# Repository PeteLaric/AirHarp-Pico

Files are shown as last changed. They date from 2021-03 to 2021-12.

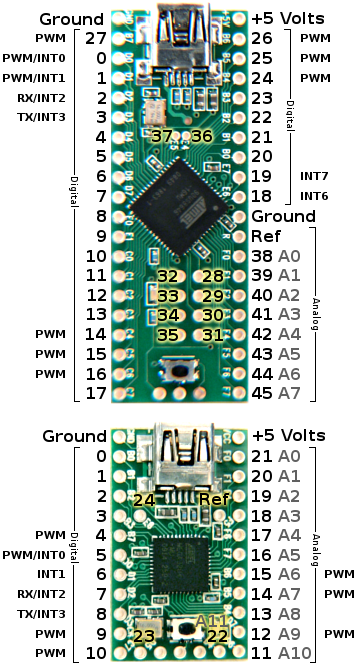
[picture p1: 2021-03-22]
misc/wiring_pinout2.png

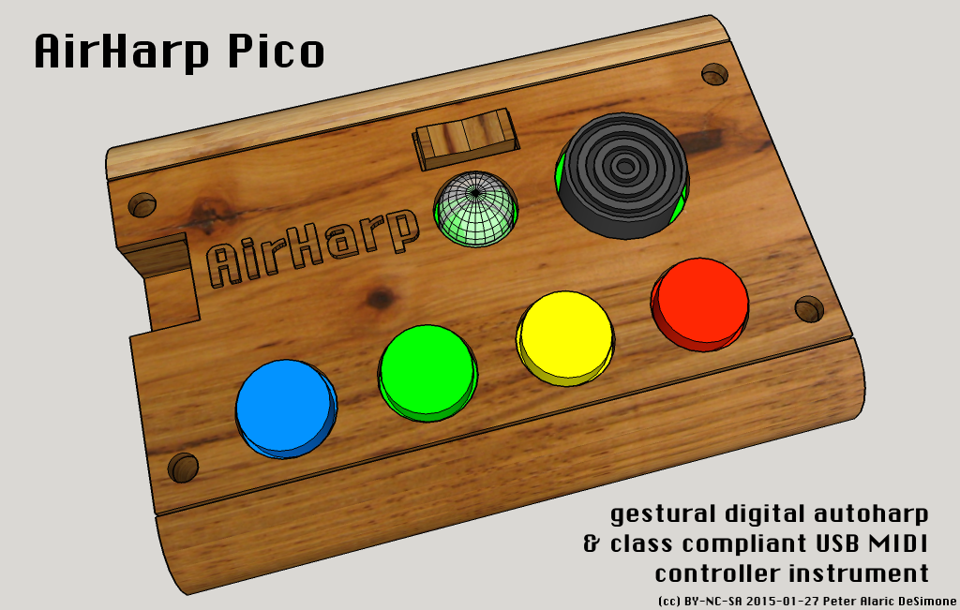
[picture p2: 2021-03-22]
render/AirHarp Pico 002 wood.png

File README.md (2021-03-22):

# AirHarp-Pico
A gestural autoharp that functions as a class-compliant USB MIDI controller instrument.

http://www.AirHarp.com

Originally conceived in 2010, the AirHarp is a gestural autoharp that allows the musician to strum chords on an invisible beam of ultrasound.  For several years, I manufactured and sold these musical instruments online.  The entire project is open source.  If you build one, please send me a note!  I'd love to see it.

Cheers,

~ Pete

http://www.PeteLaric.com

PeteLaric@protonmail.com

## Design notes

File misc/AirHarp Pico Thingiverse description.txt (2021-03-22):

AirHarp Pico
http://www.thingiverse.com/thing:676726

The AirHarp is a gestural digital autoharp that allows you to strum chords in the air on a beam of ultrasound!  The AirHarp Pico is the newest instrument in our line, with an impending Kickstarter campaign to manufacture them in quantity.  It's the best AirHarp yet, and we're confident that our customers will agree with us!

For more, check out http://www.airharp.com

Tags:

AirHarp, autoharp, MIDI controller, ultrasound, ultrasonic rangefinder, Maxbotix, Lyratron

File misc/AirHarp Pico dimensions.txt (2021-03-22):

AirHarp Pico dims
PCB: 2.8 x 1.7" (71.12 x 43.18 mm)

part locations:
part		imperial	metric
LED		<1.5, 1.1>	<38.1, 27.94>
transpose down  <1.4, 1.5>	<35.56, 38.1>
transpose up	<1.7, 1.5>	<43.18, 38.1>
S4		<.35, 0.3>	<8.89, 7.62>
RX pin		<1.95, 1.15>	<49.53, 29.21>

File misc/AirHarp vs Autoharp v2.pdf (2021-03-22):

# AirHarp vs. Autoharp

## an unfair comparison

AirHarp Pico by Lyratron | Autoharp by Oscar Schmidt

Never goes out of tune.

Goes out of tune all the damn time. Difficult and time-consuming to re-tune.

Extremely lightweight; only 3 ounces! | Heavy; shipped weight is 10.2 pounds!
Tiny; about the size of a pack of cigarettes. | Bulky; about the size of a briefcase.
Automatic transpose; play the same song in any key with the exact same fingering. | Transposing requires completely different fingering and knowledge of music theory.
Can sound like any instrument; a harp, pipe organ, electric guitar - you name it! | You're stuck with one tinny, twangy sound forever.
Play any chord without shifting your grip. | Awkward finger gymnastics.
$100 direct from Lyratron (http://www.lyratron.com/) | $289 on Amazon (http://www.amazon.com/Oscar-Schmidt-21-Chord-Autoharp/dp/B0002KMTLG)

AirHarp® is a registered trademark of Peter Alaric DeSimone. (http://www.peteralaric.com/)

Autoharp was a registered trademark of International Musical Corporation, but its registration has expired, and it is now considered a generic descriptive term for that type for instrument.

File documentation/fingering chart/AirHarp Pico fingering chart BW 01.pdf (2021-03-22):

AirHarp® Pico

Fingering Chart

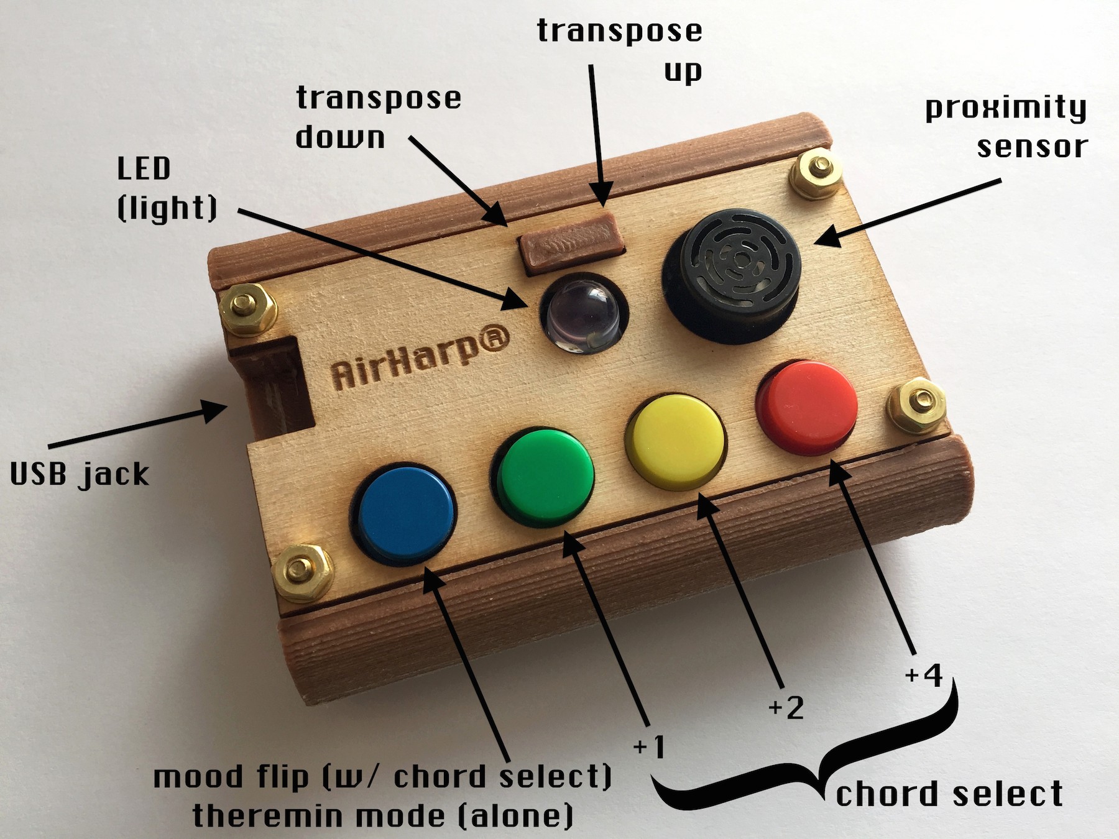
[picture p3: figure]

(cc) 2015 BY Peter Alaric DeSimone

Silence | Theremin Mode

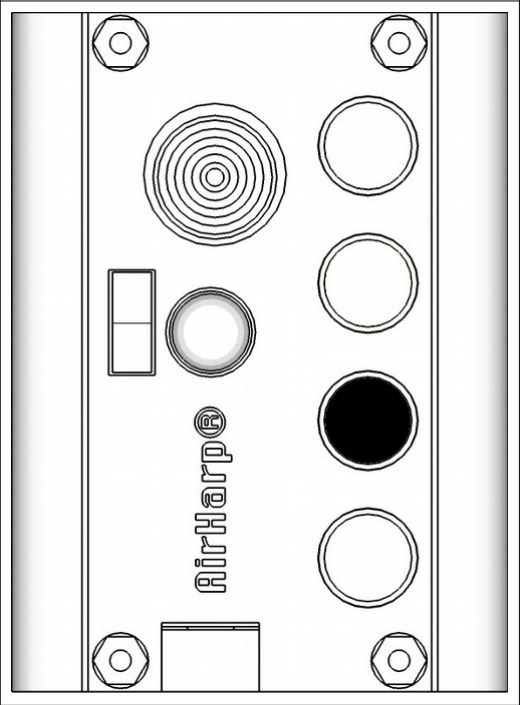
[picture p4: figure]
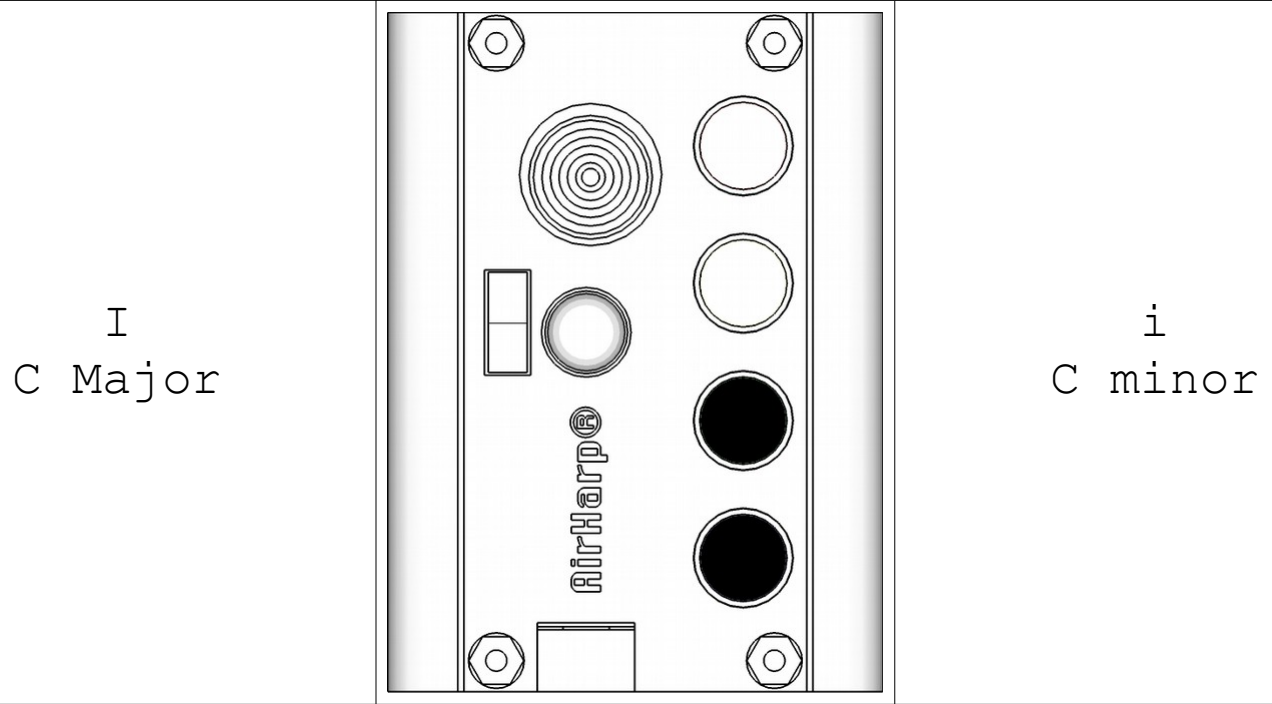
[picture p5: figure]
I C Major; i C minor
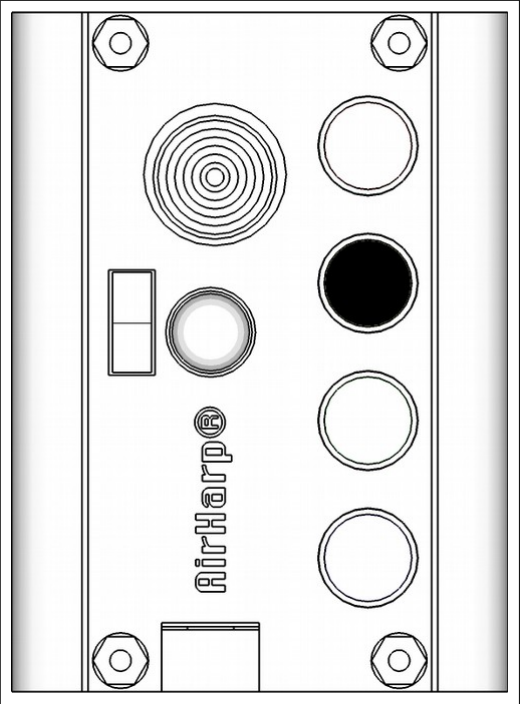
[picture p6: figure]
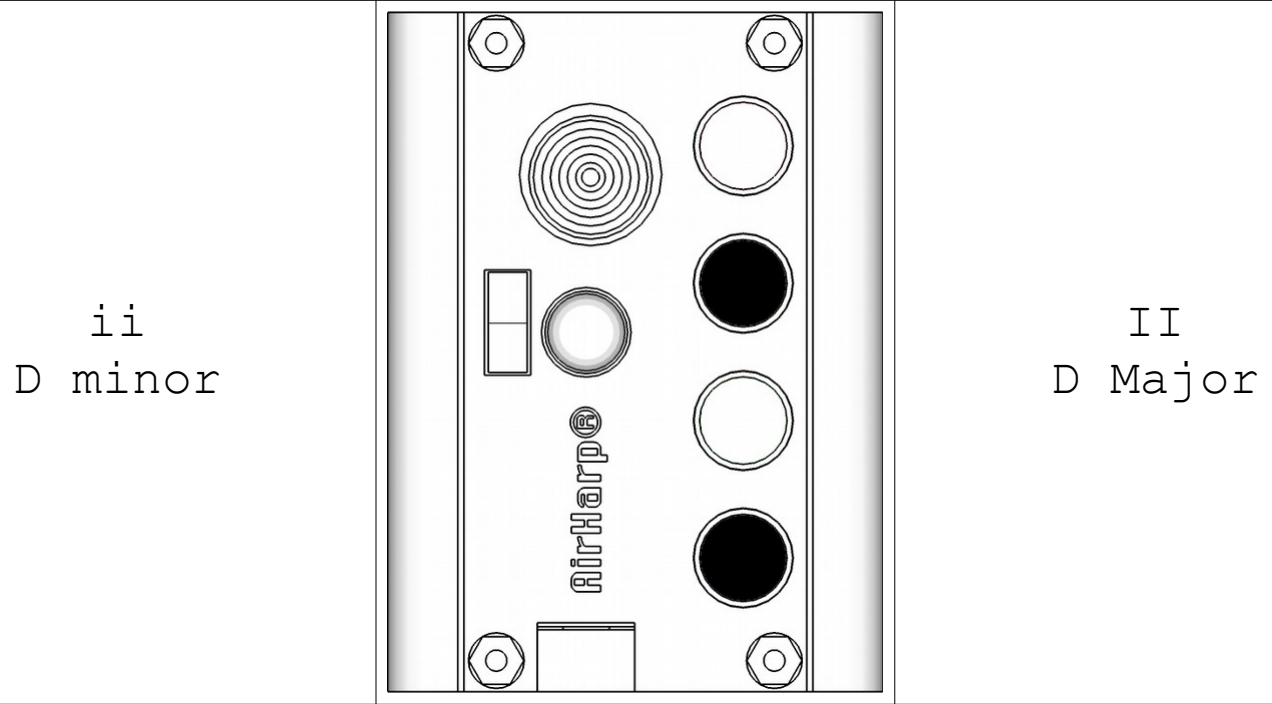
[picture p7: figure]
ii D minor; II D Major
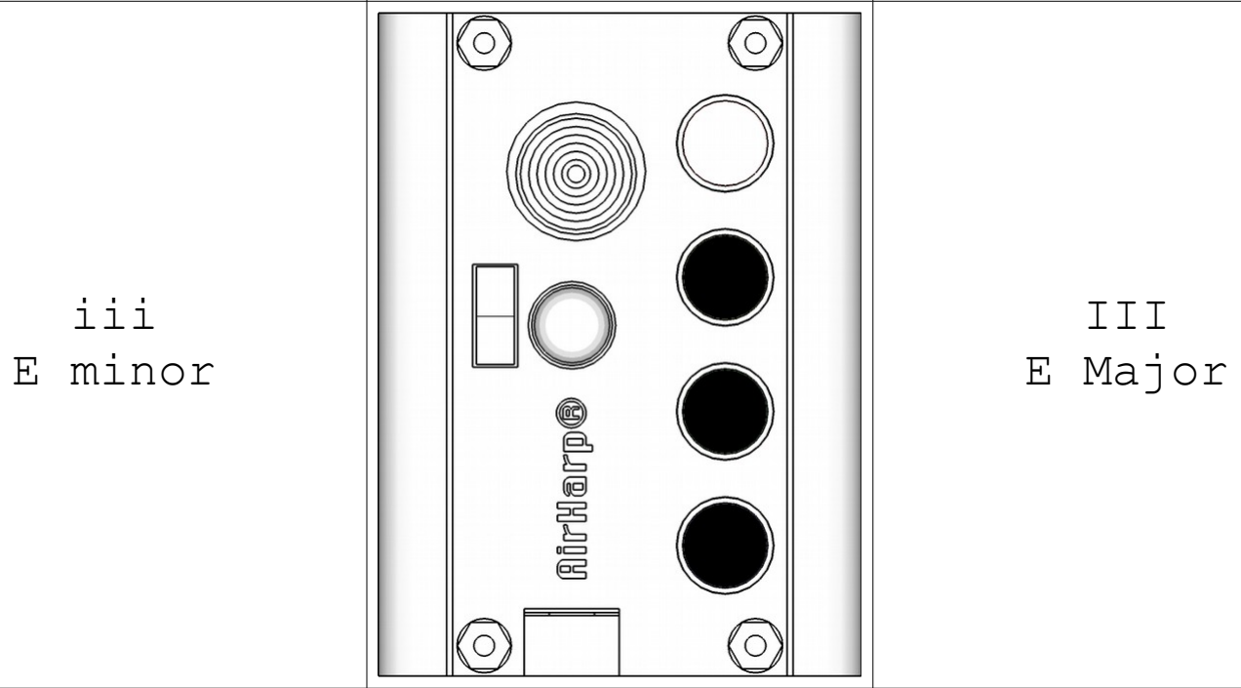
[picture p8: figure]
iii E minor; III E Major
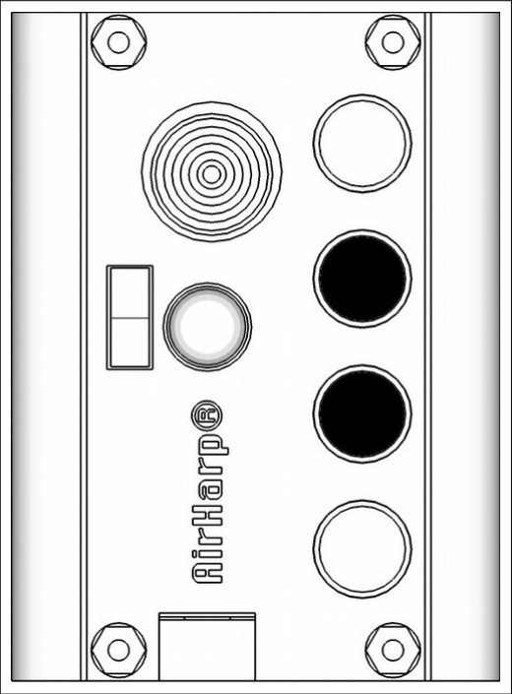
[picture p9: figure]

IV F Major | iv F minor

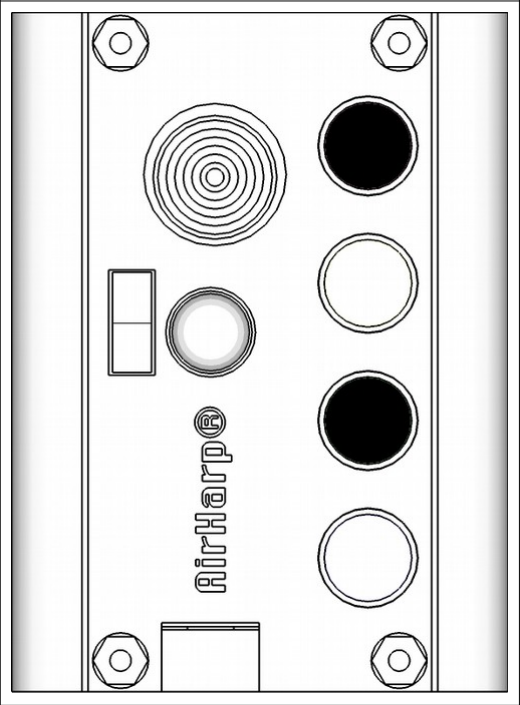
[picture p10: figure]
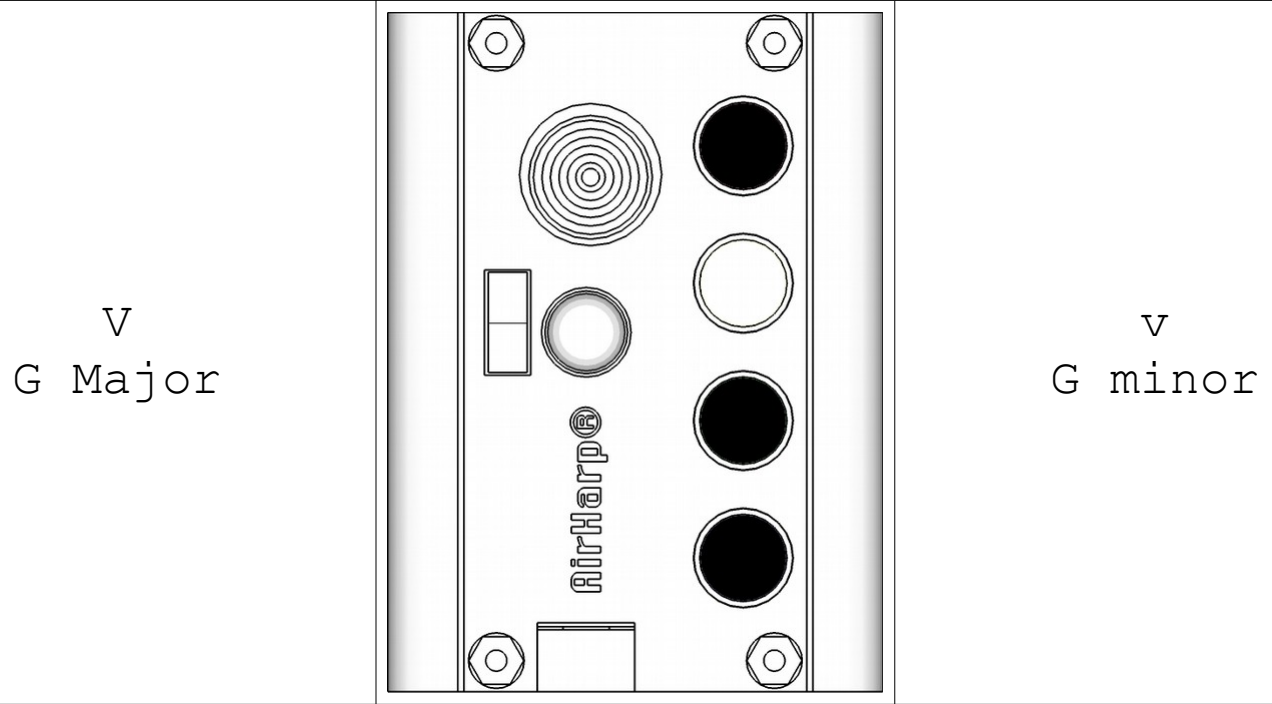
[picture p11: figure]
V G Major; v G minor
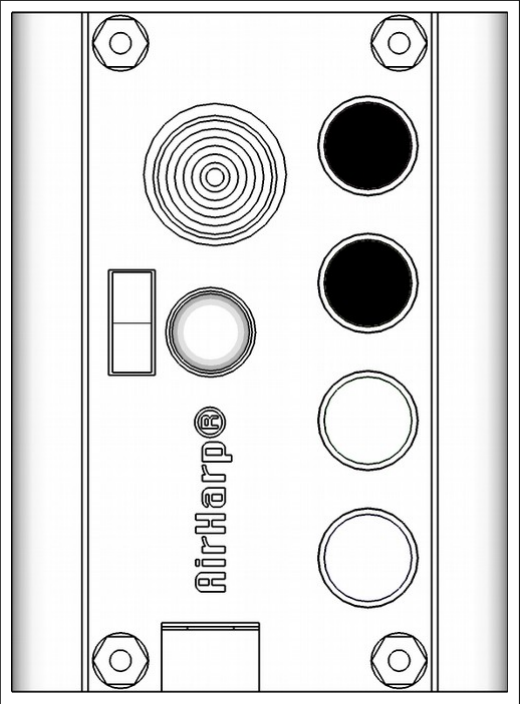
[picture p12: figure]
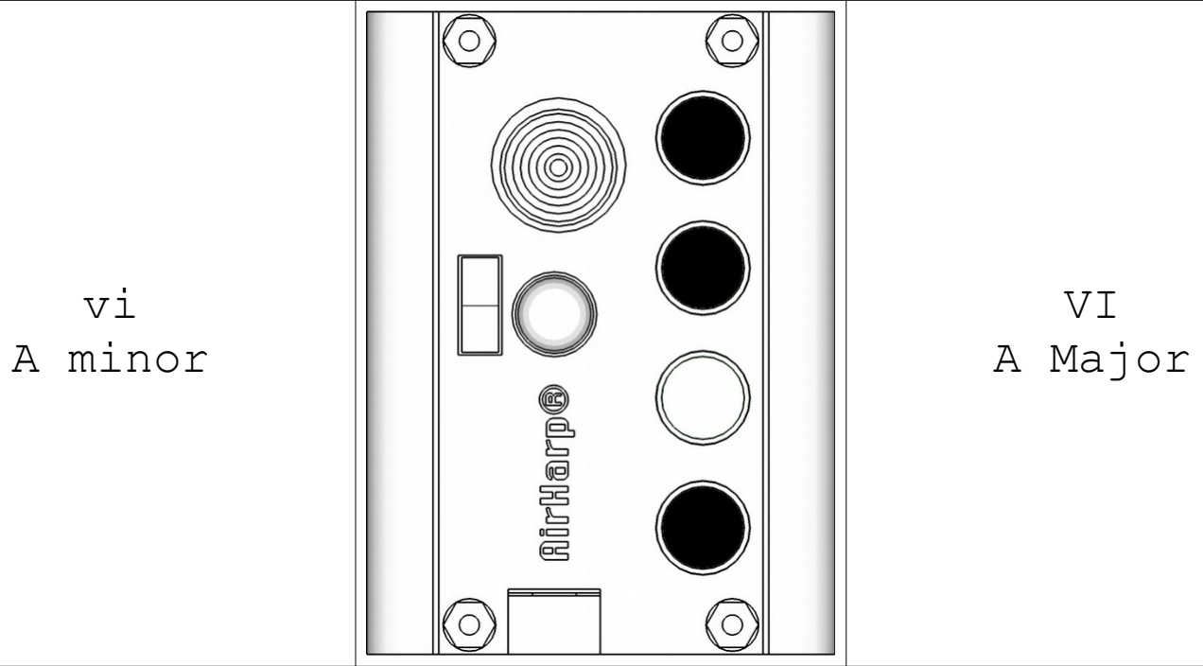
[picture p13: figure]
vi A minor; VI A Major
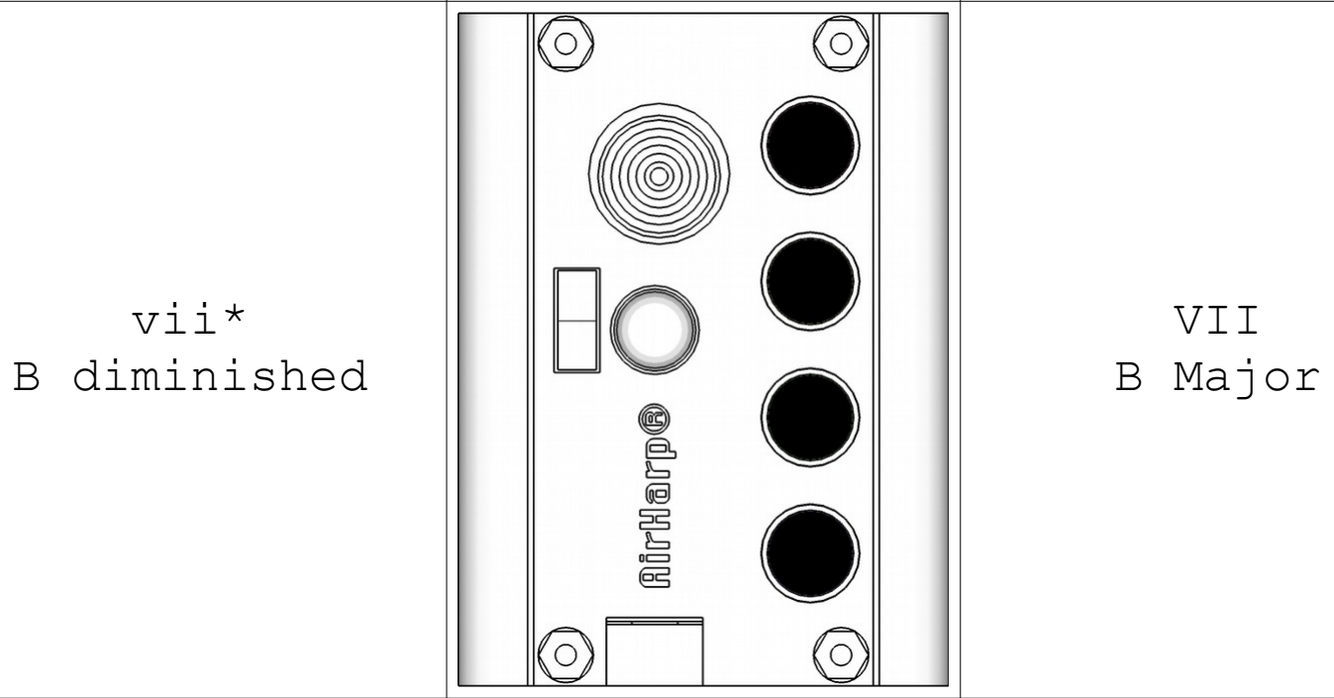
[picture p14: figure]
vii* B diminished; VII B Major
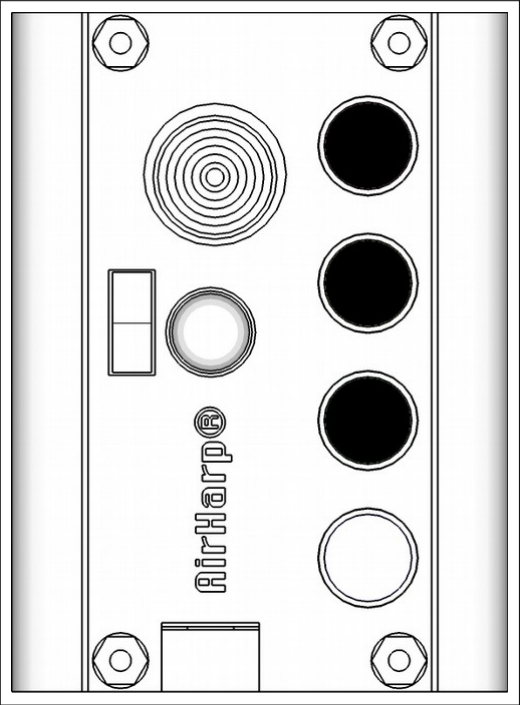
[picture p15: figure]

Transpose Up
½ Step

Transpose Down
½ Step

General Usage Notes

The AirHarp® Pico defaults to the key of C Major on boot, but can be tuned to any major key using the Transpose Up/Down buttons. To play in a minor key, simply tune to the desired key's relative major (3 half steps up from the minor key's tonic). For example, to play in the key of A minor, you would tune to the key of C Major. Since this is the AirHarp's default tuning, you don't have to do any transposing to play in the key of A minor. To play in B minor, you would tune to D Major. To achieve this, you would press the Transpose Up button twice, transposing up a whole step from C Major to D Major.

For an AirHarp to trigger a note, two conditions must be met:

1. One of the chord select buttons must be depressed.
2. The musician's hand (or some other object) must be within a predefined distance of the ultrasonic rangefinder. By default, this range is somewhere in the neighborhood of one meter.

If either one of these conditions is not met, no sound will be heard. This is by design; as with any real musical instrument, playing a note is a deliberate act, not something likely to happen by accident.

Care should be taken to avoid wiggling the USB connector while plugged into the AirHarp's USB jack. This can result in lost data packets and erratic behavior of your harp. If erratic behavior should be observed (e.g. stuck notes), simply unplug and replug your AirHarp to reboot it. Stuck notes may need to be cleared in your DAW software, which can usually be accomplished by pressing play and then pause. In Apple Logic and Apple GarageBand, simply hit the spacebar key twice.

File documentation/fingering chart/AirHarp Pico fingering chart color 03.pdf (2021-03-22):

AirHarp® Pico

Fingering Chart


(cc) 2015 BY Peter Alaric DeSimone

Silence | Theremin Mode

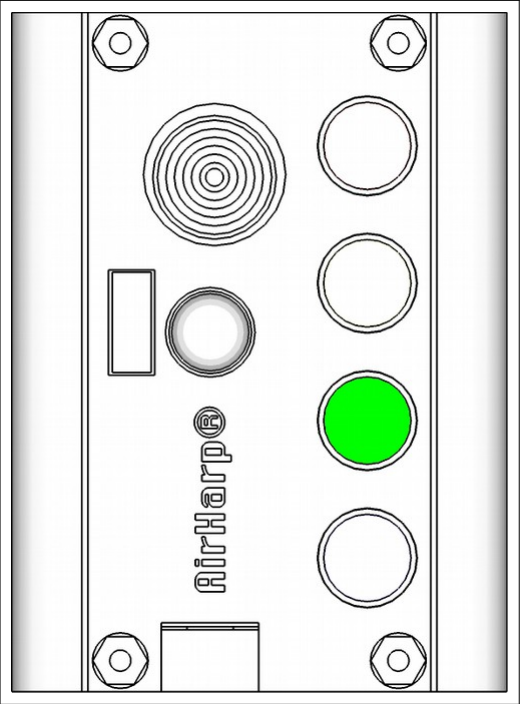
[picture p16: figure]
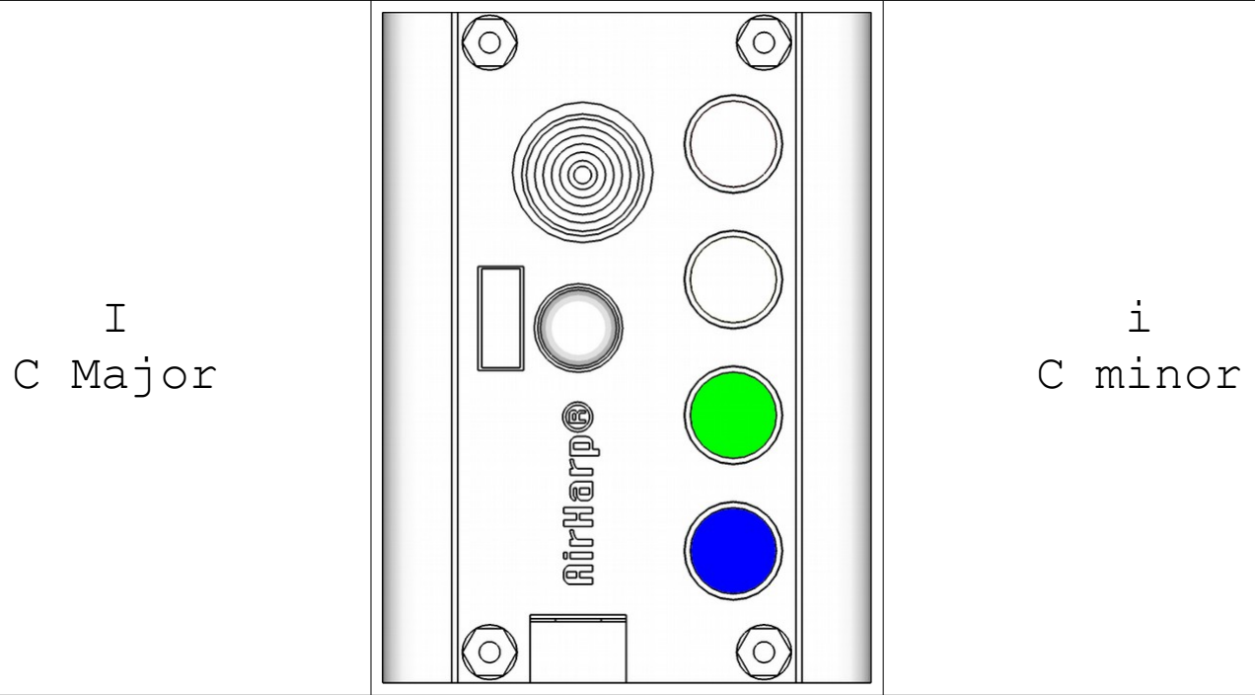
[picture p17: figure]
I C Major; i C minor
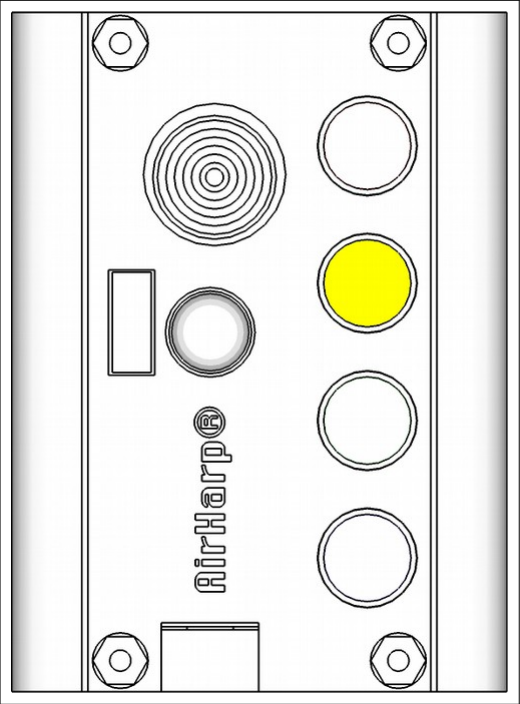
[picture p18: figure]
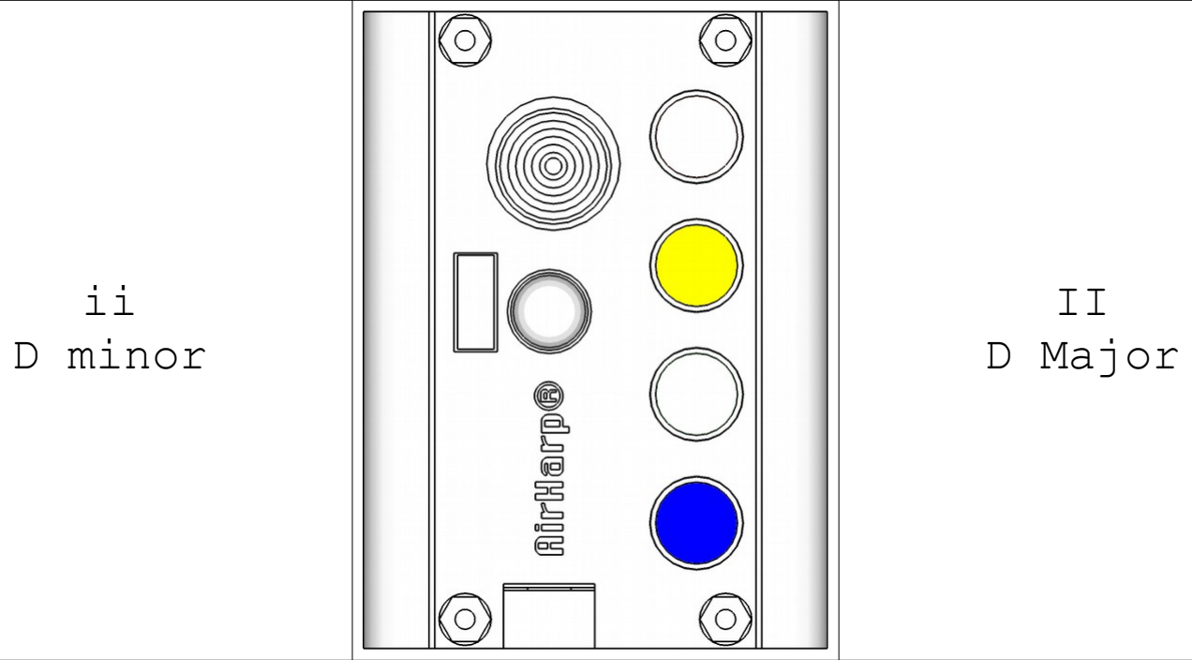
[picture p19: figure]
ii D minor; II D Major
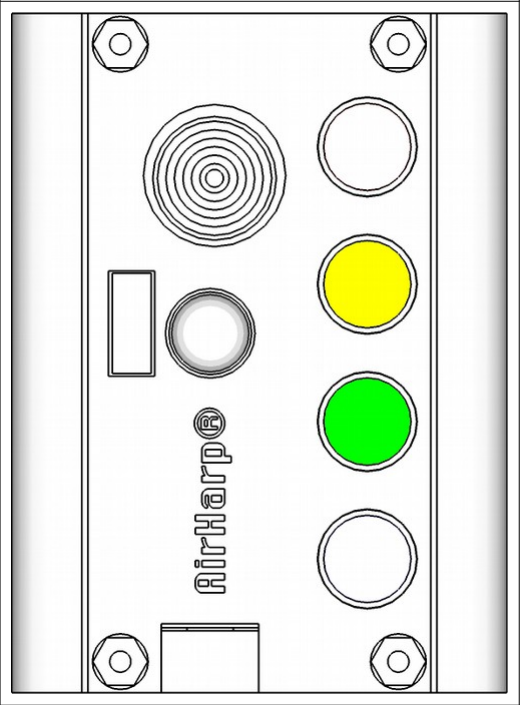
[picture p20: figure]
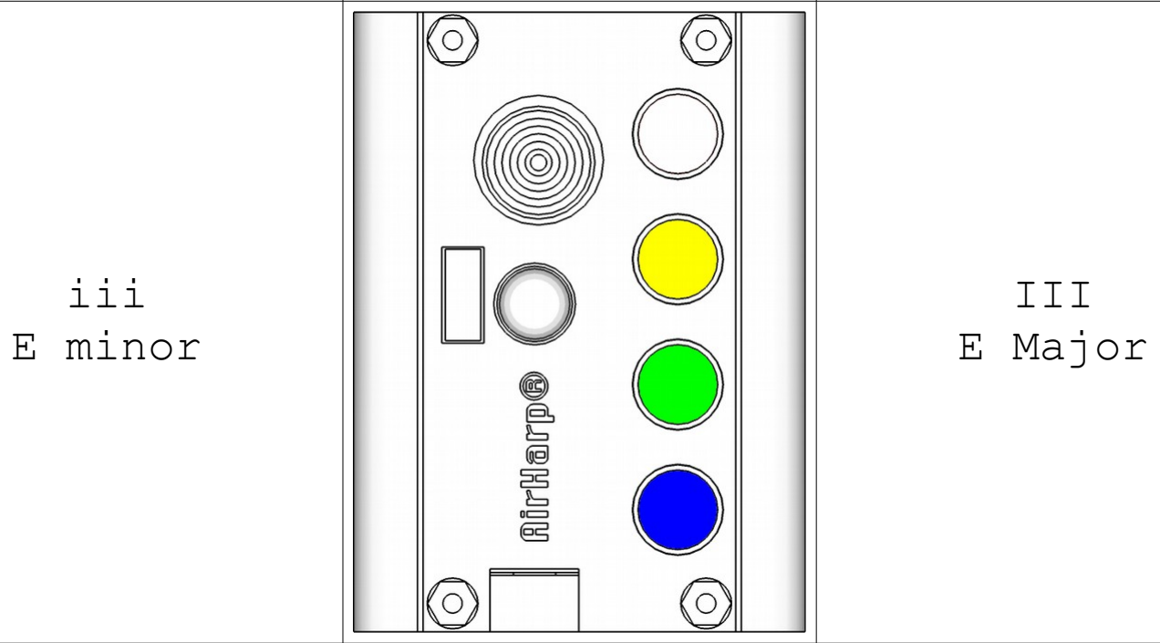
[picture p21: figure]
iii E minor; III E Major

IV F Major | iv F minor

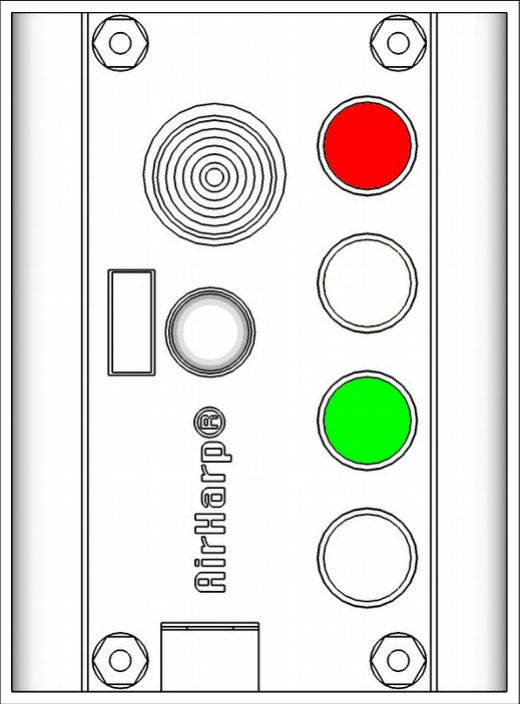
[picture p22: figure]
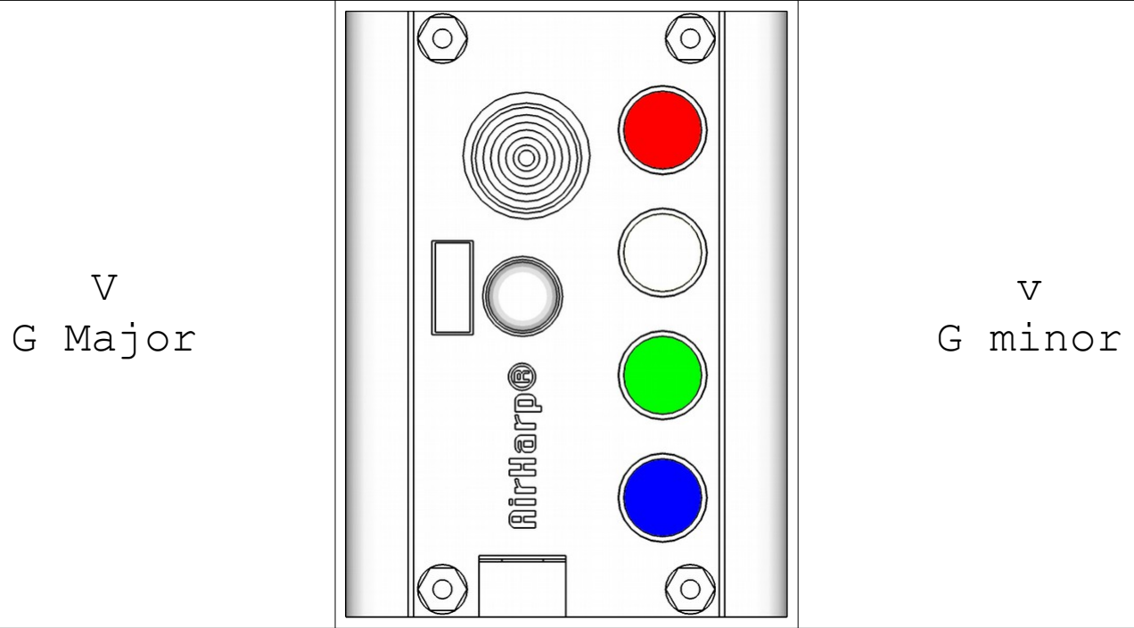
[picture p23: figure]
V G Major; v G minor
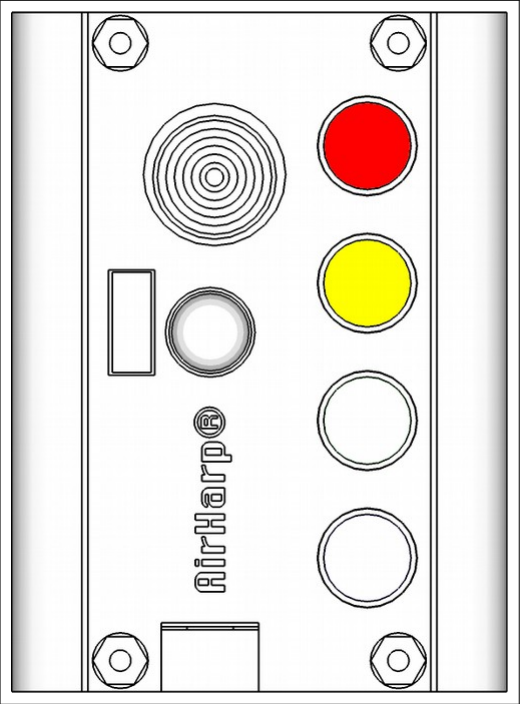
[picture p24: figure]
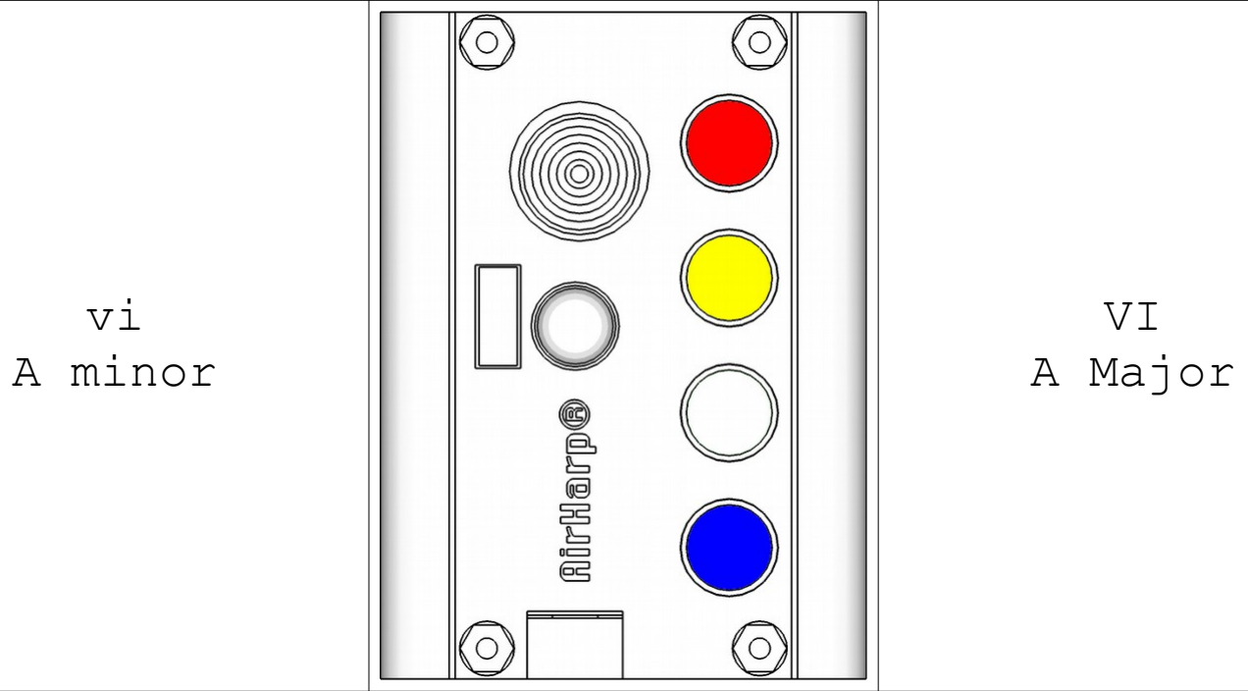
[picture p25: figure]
vi A minor; VI A Major
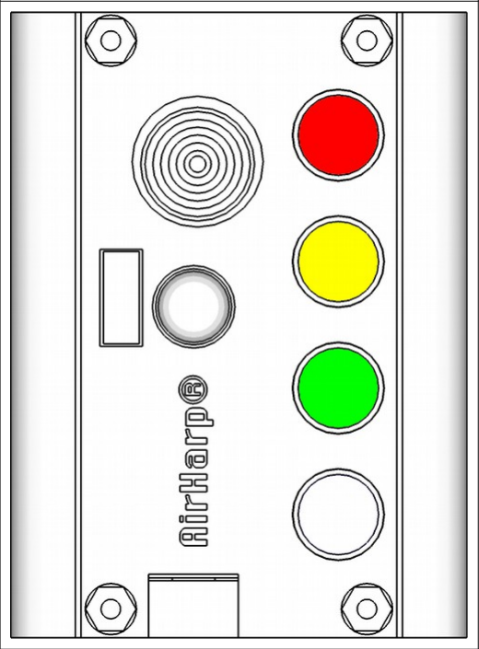
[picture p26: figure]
vii* B diminished; VII B Major

Transpose Up
½ Step

Transpose Down
½ Step

General Usage Notes

The AirHarp® Pico defaults to the key of C Major on boot, but can be tuned to any major key using the Transpose Up/Down buttons. To play in a minor key, simply tune to the desired key's relative major (3 half steps up from the minor key's tonic). For example, to play in the key of A minor, you would tune to the key of C Major. Since this is the AirHarp's default tuning, you don't have to do any transposing to play in the key of A minor. To play in B minor, you would tune to D Major. To achieve this, you would press the Transpose Up button twice, transposing up a whole step from C Major to D Major.

For an AirHarp to trigger a note, two conditions must be met:

1. One of the chord select buttons must be depressed.
2. The musician's hand (or some other object) must be within a predefined distance of the ultrasonic rangefinder. By default, this range is somewhere in the neighborhood of one meter.

If either one of these conditions is not met, no sound will be heard. This is by design; as with any real musical instrument, playing a note is a deliberate act, not something likely to happen by accident.

Care should be taken to avoid wiggling the USB connector while plugged into the AirHarp's USB jack. This can result in lost data packets and erratic behavior of your harp. If erratic behavior should be observed (e.g. stuck notes), simply unplug and replug your AirHarp to reboot it. Stuck notes may need to be cleared in your DAW software, which can usually be accomplished by pressing play and then pause. In Apple Logic and Apple GarageBand, simply hit the spacebar key twice.

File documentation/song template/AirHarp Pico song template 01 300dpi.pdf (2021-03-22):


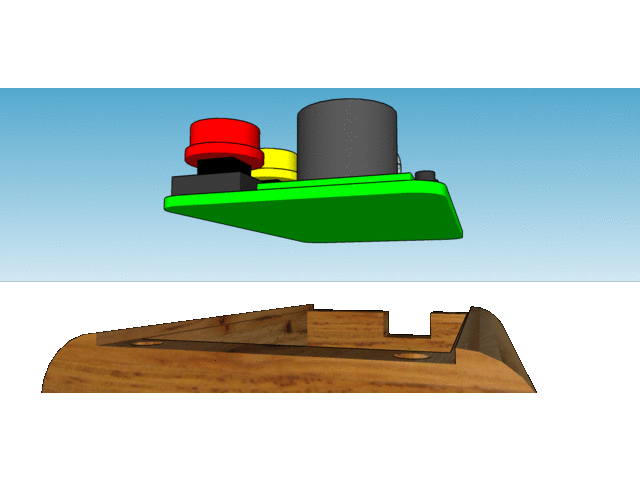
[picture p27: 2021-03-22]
render/anim/AirHarp_Pico_anim_full_large.gif

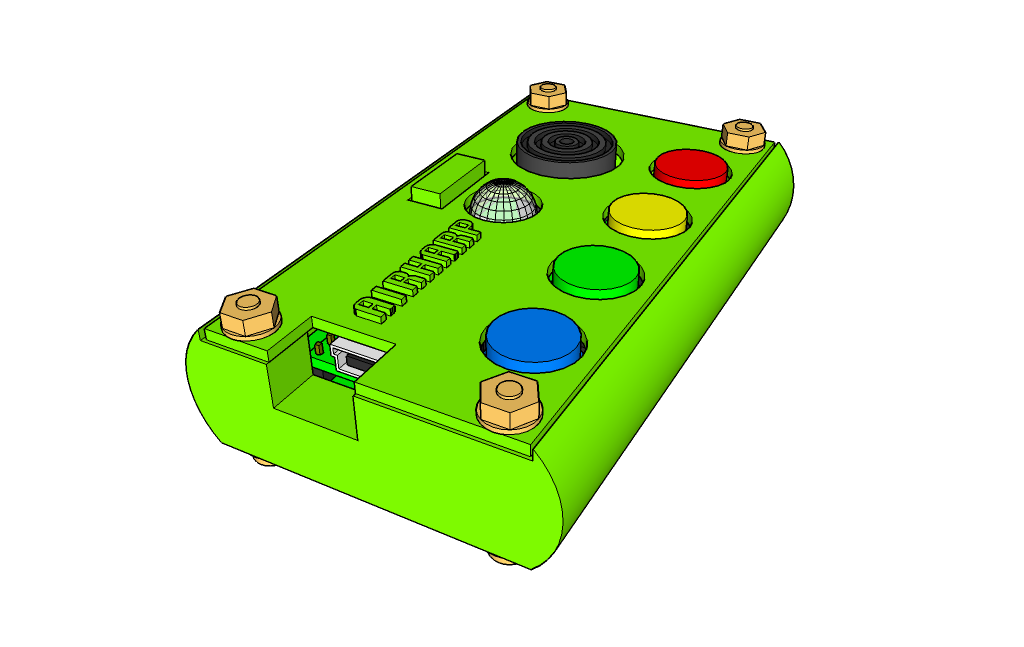
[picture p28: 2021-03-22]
render/AirHarp Pico 012 gradual curve.png

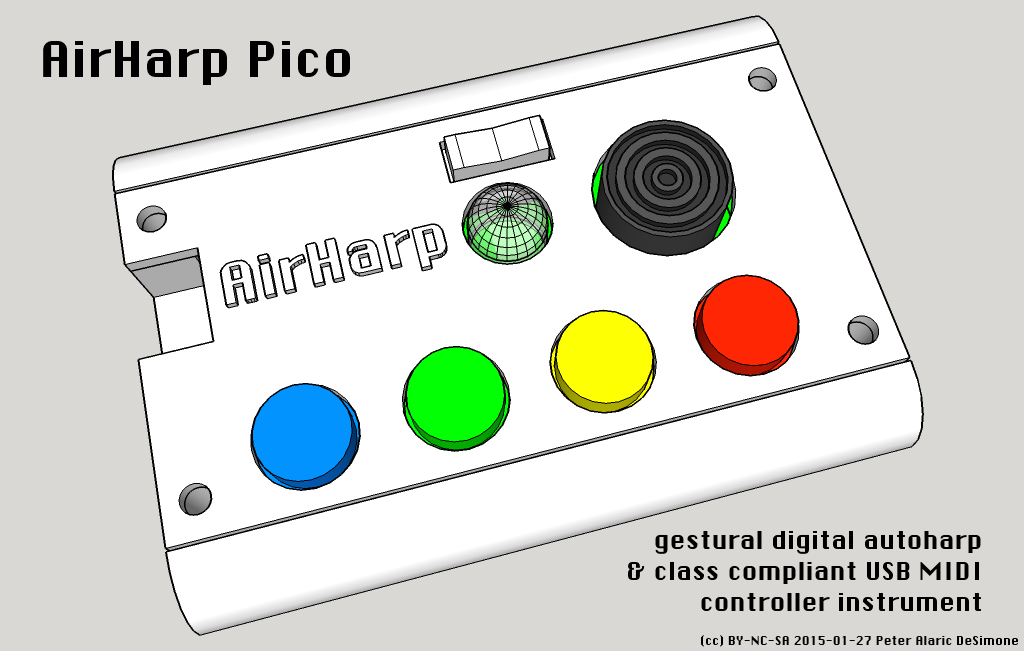
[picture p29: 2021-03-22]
render/AirHarp Pico 002 with case and transpose rocker.png

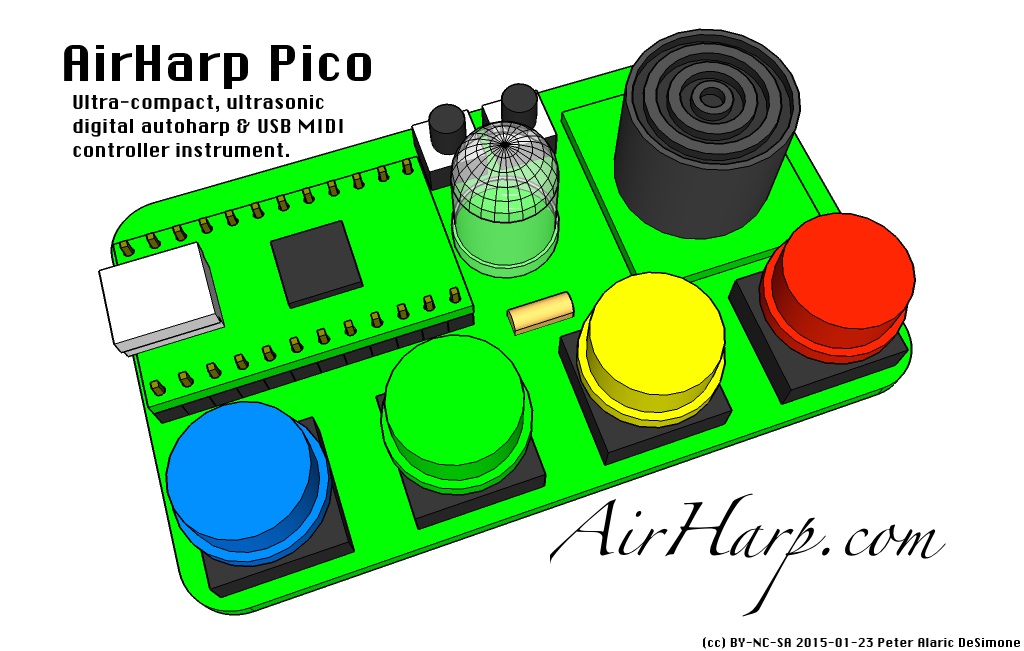
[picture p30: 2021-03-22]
render/AirHarp Pico 001 PCB SketchUp labeled.jpg

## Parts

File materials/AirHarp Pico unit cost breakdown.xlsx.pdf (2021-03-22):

Component | Cost
(USD) | Purchase
Link | Notes
MaxBotix

LV-‐EZ1

ultrasonic

rangefinder

(x1) | $22.46 https://www.adafruit.com/product/172 | $22.46 is

the

quantity:

10

cost.
Teensy

2.0

microcontroller

(x1) | $15.98 https://www.adafruit.com/products/199 | Quantity:

1
AirHarp

Pico

PCB

(x1) | $8.02 http://www.oshpark.com | Custom manufactured

part.

No

quantity

discount

from

OSH

Park.
Wood

filament

(3mm

Dark

Brown)

(51.28

g) | $2.15 http://www.amazon.com/gp/product/B00L0ZLS5U/ref=od_aui_detailpages00?ie=UTF8&psc=1 | $41.99 for

1-‐kg

spool.

Case

w/

support

material

and

rocker

switch

is

51.28g.
Tactile

Buttons,

12mm

(x4) | $1.98 https://www.adafruit.com/products/1009 | $5.95 for

3

sets.
LED

-‐

10mm

Cycling

RGB

(slow)

(x1) | $0.86 https://www.sparkfun.com/products/11452 | $0.86 is the

quantity:

10

cost.
Nuts,

brass

machine

thread,

#4-‐40

(x4) | $0.59 http://www.amazon.com/gp/product/B00HYKFGWQ/ref=oh_aui_detailpage_o01_s00?ie=UTF8&psc=1 | $14.21 for

96,

$0.148

for

1,

$0.59

for

4.
Break

away

header

strip

(x1) | $0.50 https://www.adafruit.com/products/392 | Strip includes

36

pins,

but

harp

only

requires

31,

so

5

will

be

left

over.
Midwest

Products

4402

Basswood,

1/16

x

4

x

24-‐Inch | $0.35 http://www.amazon.com/gp/product/B00081AO2A/ref=od_aui_detailpages00?ie=UTF8&psc=1 | $31.65 for

15,

2'

sheets

(30,

1'

sheets).

$1.055/sheet,

makes

3

harps.
Screws,

brass,

phillips

head,

#4-‐40x7/8"

(x4) | $0.28 http://www.amazon.com/Machine-‐Finish-‐Phillips-‐Length-‐Threads/dp/B00DD46MAC/ref=sr_1_1?ie=UTF8&qid=1427311337&sr=8-‐1&keywords=machine+screws+%234-‐40+7%2F8%22+phillips+brass $6.85
| | for

100,

$0.0685

for

1,

~$0.28

for

4.
Washers,

brass,

#4

(x8) | $0.28 http://www.amazon.com/gp/product/B009OJQE1C/ref=oh_aui_detailpage_o01_s00?ie=UTF8&psc=1 | $3.46 for

100,

$0.0346

for

1,

~$0.28

for

8.
Tactile

Button

switch

(6mm)

(x2) | $0.25 https://www.adafruit.com/products/367 | $2.50 for

20.
Resistor,

220

ohm

(x1) | $0.03 http://www.amazon.com/E-‐Projects-‐Resistors-‐Watt-‐220R-‐Pieces/dp/B00BVCCCS4/ref=sr_1_1?ie=UTF8&qid=1427309160&sr=8-‐1&keywords=resistors+220+ohm Sold
| | in lots

of

100

or

more.

Misc

costs:

solder,

electricity

to

run

machines,

etc. (negligible)

Total

Cost: | $53.73 http://lyratron.com/Lyratron/Store.html

AirHarp®

Pico

Unit

Cost

Breakdown

with

Purchase

Links

©2015

Lyratron

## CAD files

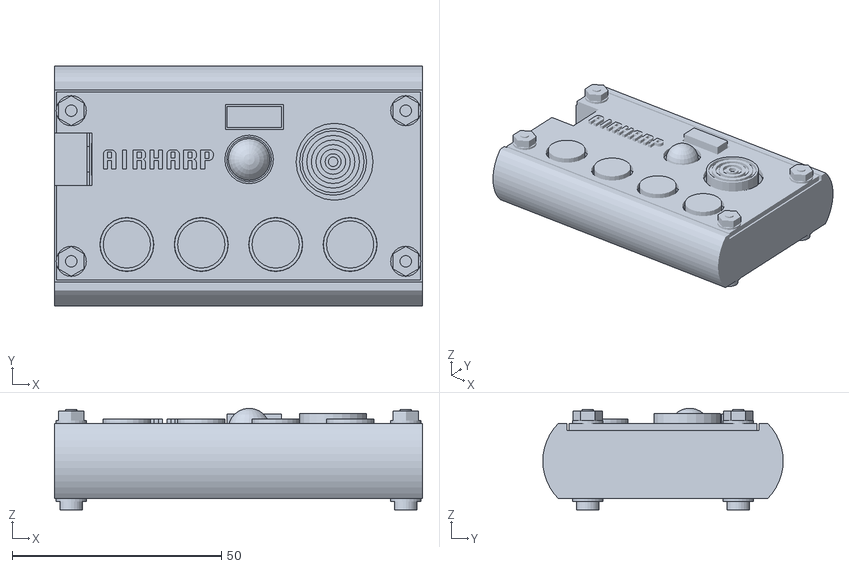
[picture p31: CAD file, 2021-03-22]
3D CAD/AirHarp Pico 013 assembled.stl
87.9 x 57.4 x 24.3

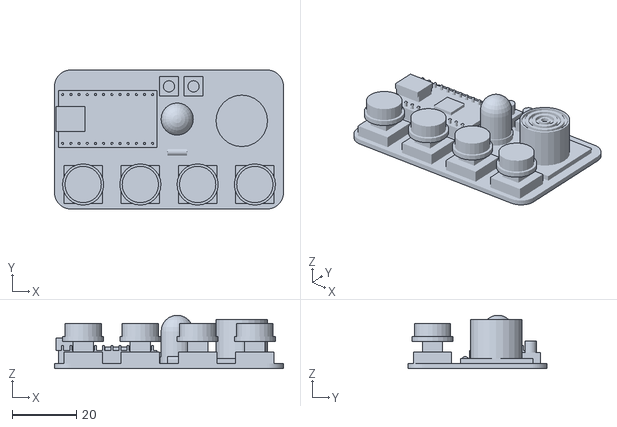
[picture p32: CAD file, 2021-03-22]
3D CAD/AirHarp Pico 013 PCB.stl
71.1 x 43.2 x 16.6

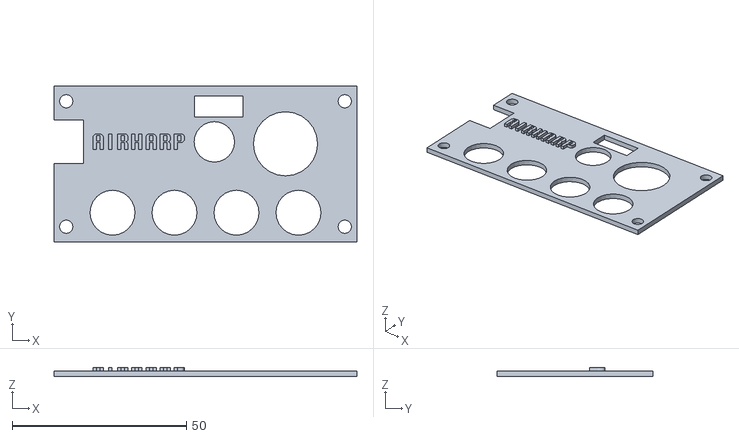
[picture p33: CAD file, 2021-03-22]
3D CAD/AirHarp Pico 013 top.stl
86.9 x 44.9 x 2.66

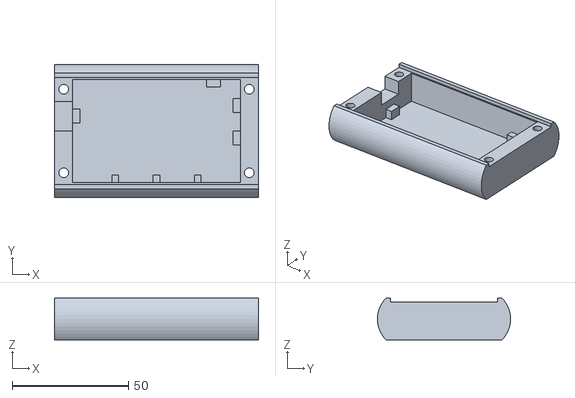
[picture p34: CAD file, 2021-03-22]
3D CAD/AirHarp Pico 013 bottom.stl
87.9 x 57.4 x 18.0

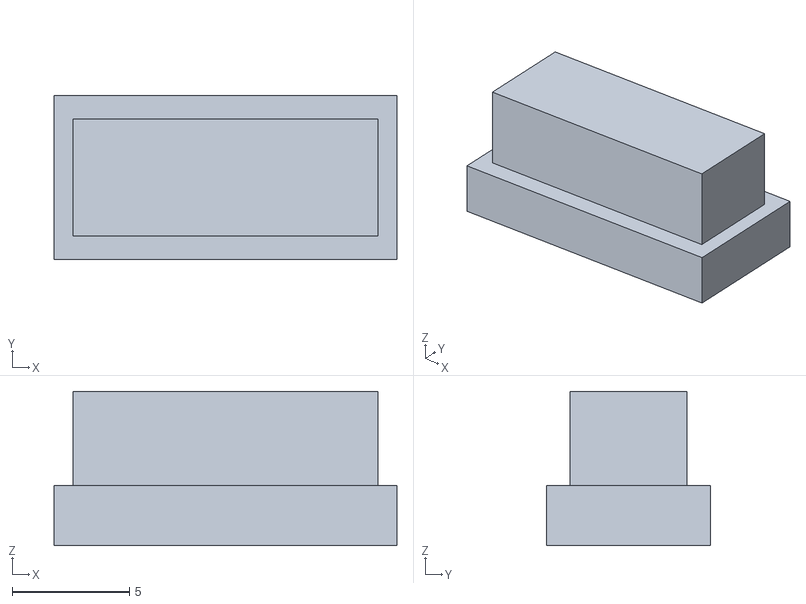
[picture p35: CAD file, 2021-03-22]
3D CAD/AirHarp Pico 013 rocker.stl
14.6 x 7.00 x 6.57

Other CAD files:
3D CAD/AirHarp Pico 013.skp

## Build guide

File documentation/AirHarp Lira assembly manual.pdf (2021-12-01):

Building the AirHarp Lira r3 | 1) Collect Parts

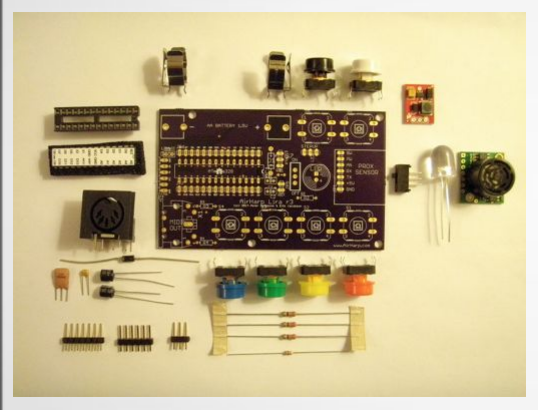
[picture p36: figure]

- | AirHarp Lira circuit board (1) ● | Maxbotix LV-EZ1 ultrasonic rangefinder (1) ● | 10mm color-changing LED (1) ● | SPDT power switch (1) ● | 5v step-up circuit (1) ● | 12mm colored momentary buttons (6) ● | 220 ohm resistors (3) ● | 10 kilohm resistor (1) ● | Break away headers (7+6+3=16 pins) ● | 10uF electrolytic capacitors (2) ● | .1uF ceramic capacitor (1) ● | 16 MHz ceramic resonator (1) ● | 1N5819 Schottky diode (1) ● | DIN-5 MIDI jack, female (1) ● | ATmega328 microcontroller (1) ● | 28-pin DIP socket (1) ● | AA battery holders (2)

## 2) Insert black button

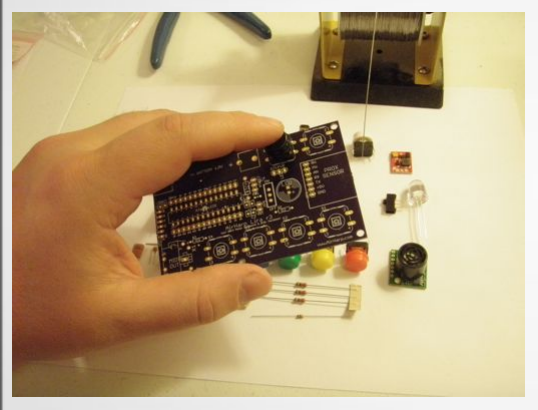
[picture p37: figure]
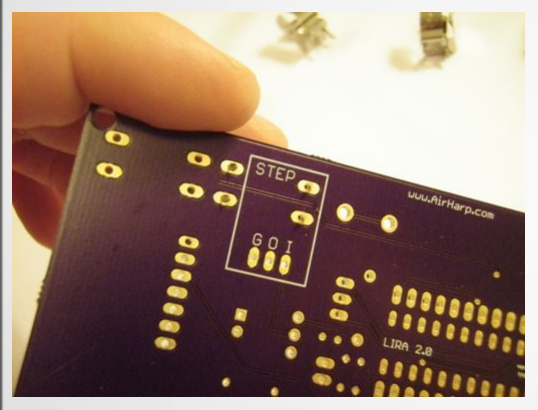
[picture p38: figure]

Order of many steps doesn't matter,

### but black button must be installed

prior to installation of step up.

## Here's why!

### Leads from the black button protrude from the underside of the board, right where the

voltage step up circuit will be mounted.

### If you don't solder them now, you won't be

able to get to them later.

3) Solder and trim black button leads | 4) Solder pins to step up module

## 5) Insert step up module into bottom of board

Trim these pins that protrude from the bottom.

## 6) Solder step up pins on top side of main board

## 7) Insert pins into ultrasonic rangefinder

### Insert from top, such that plastic part of pin strip

is on top and bare pins protrude from bottom.

## 8) Solder pins to ultrasonic rangefinder

This step is very important! If you skip this step, there will be no electrical connection

### between the main board and the ultrasound, and your AirHarp will not work!

## 9) Solder rangefinder to main board

Insert rangefinder from top; solder on bottom.

## 10) Trim leads on top of rangefinder

These vertically protruding leads can present case clearance issues. Best to trim them now while you can still get to them.

## 11) Install LED

Insert from top and solder in place. Trim leads.

## 12) Install power switch

Insert from top and solder in place.

## 13) Install Schottky diode

Solder and trim leads.

## Soldering Tip

When working with small parts such as diodes and resistors, splaying the leads like this helps to retain the part in place during soldering.

## 14) Install the ceramic resonator

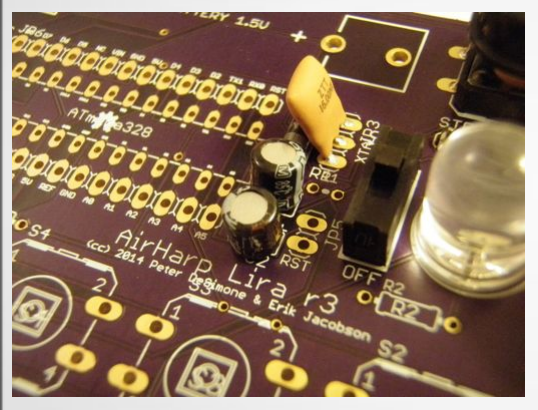
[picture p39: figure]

### Bend it slightly over the diode. This is for

case clearance purposes.

## 15) Install the electrolytic capacitors

### When working with electrolytic caps, getting the polarity right is very important! There's a white stripe along the side of each cap. This is the negative side. There are marks on the

circuit board showing which side is negative.

### Note that the caps may be facing different directions from each other. That's okay! Always go with the polarity indicated on the

circuit board.

## 16) Insert chip socket

### Note that the little tick mark on the right aligns

with the mark on the board.

## 17) Solder chip socket in place

### Tip: Solder the four corners of the chip

socket first. It will stay in place thereafter.

## 18) Install programming header

### Make sure the pins are installed from the top with the long side facing up!

## 19) Install battery clips

These things are basically giant heat sinks, so heating them up can take a while. Try not to burn yourself in the process!

## 20) Install the ceramic capacitor

Polarity doesn't matter on this one.

## 21) Install the 10k resistor

Polarity doesn't matter with resistors.

22) Install 220 ohm resistors R3 and R4 | 23) Install 220 ohm resistor R2
24) Install DIN-5 MIDI jack | 25) Install buttons

## 26) Bend microcontroller pins

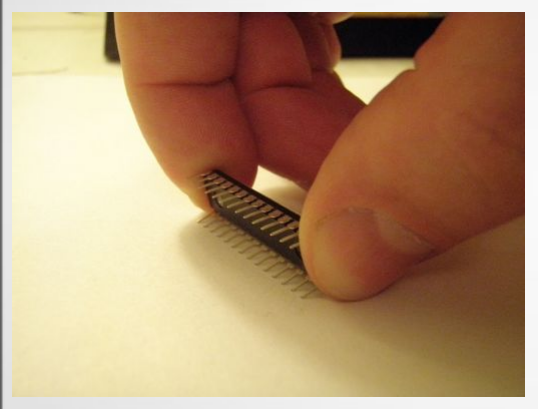
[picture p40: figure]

### The pins on the ATmega328 microcontroller tend to splay outward from the factory, and the chip socket is too narrow to accommodate them as-is. To fix this, bend the pins inward gently against a flat surface; just enough such that they are bowed slightly inward instead of

outward.

## How we bend the chip pins

Here's a method of bending the chip pins that works well for us. Grab the chip body on each end and gently roll it against the table.

## 27) Insert the chip

IMPORTANT: Make sure the hash mark on the chip lines up with the mark on the board, and on the chip socket! In this picture, the hash mark is on the right.

## Programming

Your board is physically done, but you need to program it. To do that, you'll need an FTDI serial breakout board, like this one.

## 28) Connect FTDI

Connect the FTDI to a mini-USB cable, and plug it into the programming header. Note that “chip faces chip”! Connect mini-USB to computer.

## 29) Load AirHarp firmware in Arduino IDE

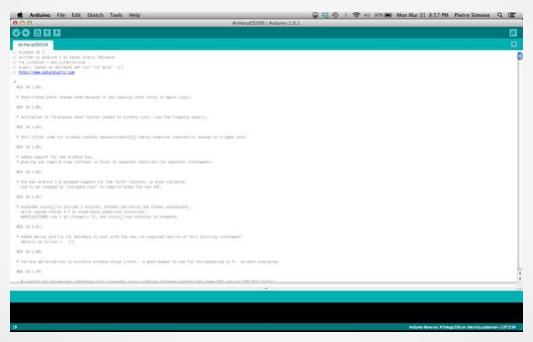
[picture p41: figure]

### The latest AirHarp firmware should always be available at http://www.airharp.com

## 30) Select board

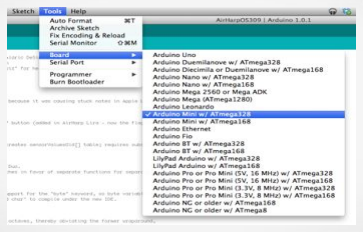
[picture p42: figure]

Select Tools-->Board-->Arduino Mini w/ ATmega328

## 31) Select serial port

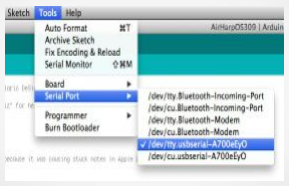
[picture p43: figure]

Select Tools-->Serial Port-->/dev/tty.usbserial-SOMEJUNK

## 32) Upload firmware

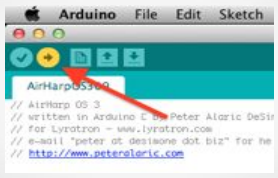
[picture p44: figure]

### Press Command+U, or click the little arrow to the right

of the check mark in the bar at the top of the sketch.

## 33) Upload complete!

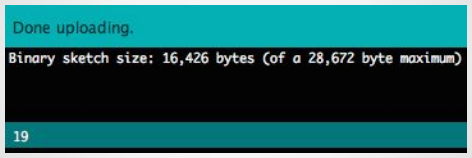
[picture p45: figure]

### You should see a message like this at the bottom of the screen. If so, you're done!

## 34) If you love it, put a case on it!

### We won't discuss the specifics of case assembly in this document, because there are

currently too many options and we're still in the process of deciding which will be standard.

## 35) Test it!

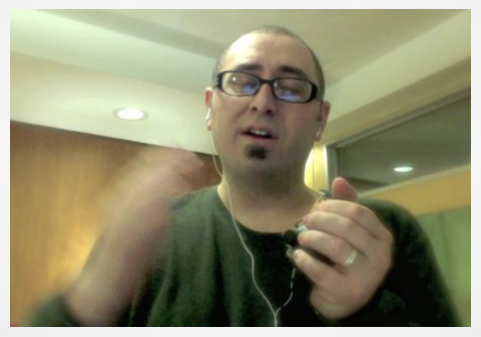
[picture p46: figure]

This is perhaps the most vital step in the entire process. No product will ever leave our shelves without being thoroughly tested! If it doesn't work, Peter can help you find out why.

## Disclaimer / Acknowledgements

This document is meant to supplement, not replace, a basic knowledge of electronics and soldering procedures. Builders are encouraged to familiarize themselves with the process prior to building an AirHarp to avoid damage to components and/or personal injury. Building an AirHarp Lira is a fairly advanced undertaking and is probably unsuitable as an introductory electronics project (unless the amateur builder has guidance from someone with more experience).

This instruction manual was written by Peter Alaric DeSimone, inventor of the AirHarp. The AirHarp Lira was developed jointly by Peter, who designed the electronics and coded the firmware, and Erik Jacobson, who designed the ergonomic polymer case. Aspects of the design were suggested by an enigmatic inventor

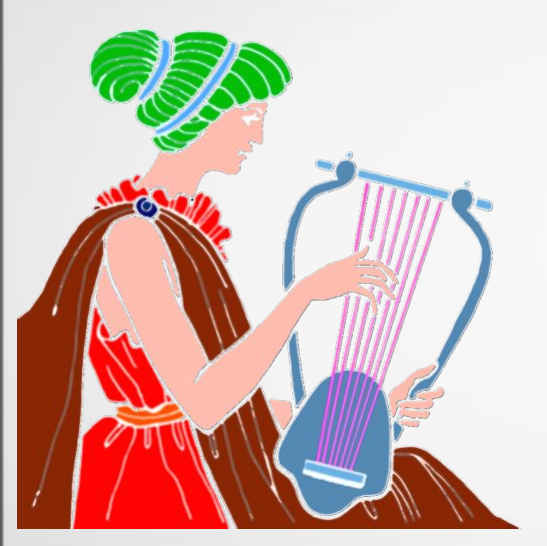
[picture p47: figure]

who goes by the moniker SouthernAtHeart. http://www.lyratron.com

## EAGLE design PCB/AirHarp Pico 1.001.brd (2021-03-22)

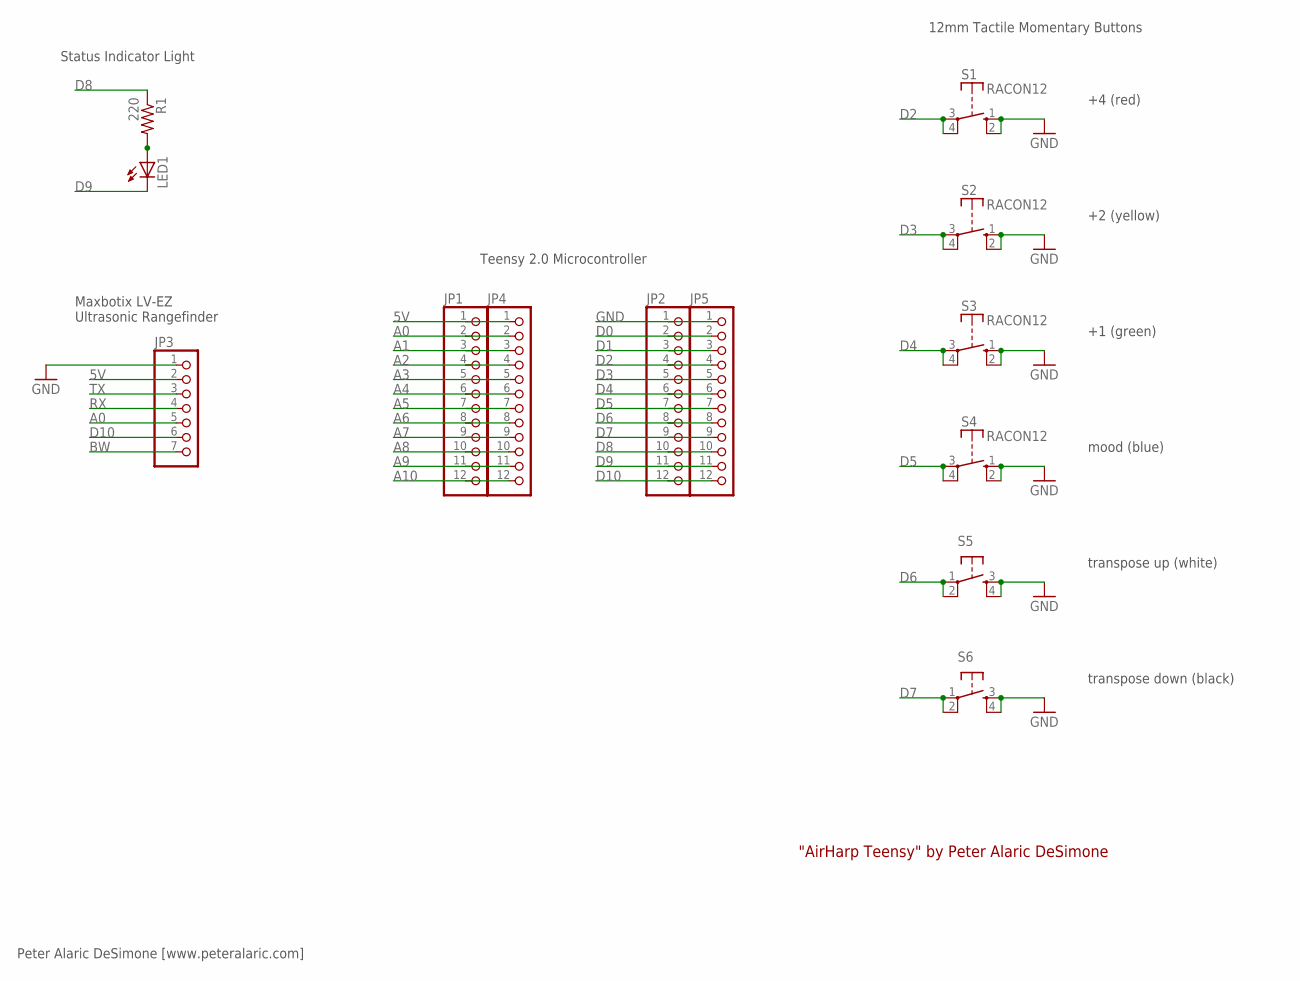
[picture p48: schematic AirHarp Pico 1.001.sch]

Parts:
JP1, JP2, JP4, JP5: PINHD-1X12; 1X12
JP3: PINHD-1X7; 1X07
LED1: LED10MM
R1: 220; 0207/7
S1, S2, S3, S4: RACON12
S5, S6: TAC_SWITCHPTH; TACTILE-PTH

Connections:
5V: JP1.1, JP3.2, JP4.1
A0: JP1.2, JP3.5, JP4.2
A1: JP1.3, JP4.3
A2: JP1.4, JP4.4
A3: JP1.5, JP4.5
A4: JP1.6, JP4.6
A5: JP1.7, JP4.7
A6: JP1.8, JP4.8
A7: JP1.9, JP4.9
A8: JP1.10, JP4.10
A9: JP1.11, JP4.11
A10: JP1.12, JP4.12
BW: JP3.7
D0: JP2.2, JP5.2
D1: JP2.3, JP5.3
D2: JP2.4, JP5.4, S1.3, S1.4
D3: JP2.5, JP5.5, S2.3, S2.4
D4: JP2.6, JP5.6, S3.3, S3.4
D5: JP2.7, JP5.7, S4.3, S4.4
D6: JP2.8, JP5.8, S5.1, S5.2
D7: JP2.9, JP5.9, S6.1, S6.2
D8: JP2.10, JP5.10, R1.1
D9: JP2.11, JP5.11, LED1.K (C)
D10: JP2.12, JP3.6, JP5.12
GND: JP2.1, JP3.1, JP5.1, S1.1 (S), S1.2 (S), S2.1 (S), S2.2 (S), S3.1 (S), S3.2 (S), S4.1 (S), S4.2 (S), S5.3, S5.4, S6.3, S6.4
unnamed: LED1.A, R1.2
RX: JP3.4
TX: JP3.3

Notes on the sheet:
"AirHarp Teensy" by Peter Alaric DeSimone
Peter Alaric DeSimone [www.peteralaric.com]
Maxbotix LV-EZ Ultrasonic Rangefinder
12mm Tactile Momentary Buttons
Teensy 2.0 Microcontroller
+4 (red)
+2 (yellow)
+1 (green)
mood (blue)
transpose up (white)
transpose down (black)
Status Indicator Light

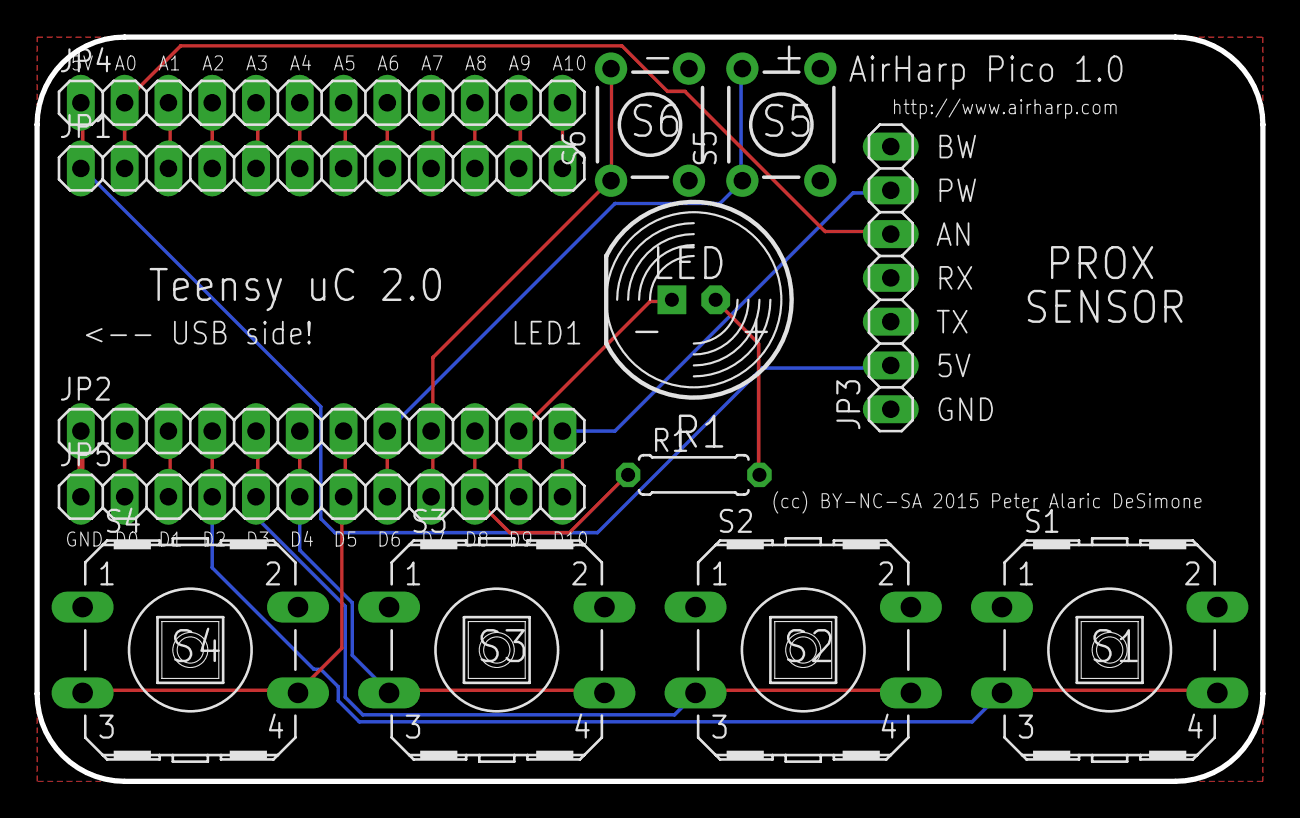
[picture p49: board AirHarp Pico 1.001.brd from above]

Board: 2 copper layers, 71.1 x 43.2 mm, 13 parts (0 on the bottom side), 25 nets.

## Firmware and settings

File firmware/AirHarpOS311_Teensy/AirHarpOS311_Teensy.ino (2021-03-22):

// AirHarp OS 3
// written in Arduino C by Pete Laric
// http://www.PeteLaric.com

/*
  NEW IN 3.11 Teensy:
  
  * experimented with pulseIn() rather than analogRead().  it's too slow.
  
  NEW IN 3.10 Teensy:
  
  * shoehorned code into running on Teensy 2.0-based AirHarp Pico.
  * code is now forked.

  NEW IN 3.09:

  * Deactivated patch change mode because it was causing stuck notes in Apple Logic.

  NEW IN 3.08:
  
  * Activation of "transpose down" button (added in AirHarp Lira - now the flagship model).
  
  NEW IN 3.06:
  
  * anti-jitter code for AirHarp creates sensorValuesOld[] table; requires substantial change to trigger note.

  NEW IN 3.05:
  
  * added support for new AirHarp Duo.
  * phasing out compile time switches in favor of separate functions for separate instruments.
  
  NEW IN 3.04:
  
  * the new Arduino 1.0 dropped support for the "byte" keyword, so byte variables
    had to be changed to "unsigned char" to compile under the new IDE.

  NEW IN 3.02:
  
  * expanded scale[] to include 2 octaves, thereby obviating the former wraparound,
    which caused chords 4-7 to experience undesired inversions.
    NUMSCALETONES now = 14 (formerly 7), and scale[] now contains 14 elements.

  NEW IN 3.01:
  
  * added device profile for HaloHarp to work with the new, re-imagined version of this exciting instrument!
    details to follow...  ;?)

  NEW IN 3.00:

  * various optimizations to minimize AirHarp strum jitter.  a good number to use for stringSpacing is 4.  no more averaging!

  NEW IN 2.99:
  
    * support for driverless interface with Lyrasynth cross-platform software synthesizer (does NOT require USB MIDI hack!)
    * automatic switching of majorSevenMode (AirHarp only).

  NEW IN 2.98:
  
    * beaconMode added for new AirHarp USB (first commercial AirHarp!)  the AirHarp Shield v1.2 now features an LED
    (with series resistor) between pins D12 & D13.  the LED's negative pin goes to 12 and its positive goes to 13.
    thus, the direction of current flow could be reversed in firmware to support a bi-color LED.

  NEW IN 2.97:
  
    * modified transpose button code to work with 5-button AirHarps.

  NEW IN 2.96:
  
    * alwaysTriggeredMode allows diagnostic use of an AirHarp lacking a rangefinder.
    
  NEW IN 2.95:
  
    * velocity keyed to strum speed (didn't like this mode as much as i thought i would).
    * multichannel MIDI output, w/ chordChannel playing fixed, root-position chords and strumChannel playing monophonic strum tones.

  NEW IN 2.94:
  
    * published to AirHarp.com for the first time.

  NEW IN 2.93:
  
    * added support for selecting MIDI channel (limited to 1 channel only, since only 1 midi velocities array exists).
    
  NEW IN 2.91:
  
    * gutted unused code to make LHOS smaller.
    * removed servo support.
    * discovered that aforementioned autoDetectUSB code was in fact executing, but serial debugging wasn't working
      because the debug data rate hadn't been set yet.  doh!
    * decided that autoDetectUSB was more trouble than it's worth from a hardware perspective.  i'll leave the code dormant for now.
    * Mr. K informed me that i could recompile the USB MIDI driver with a 31250 data rate.  problem solved.
    * PRINTED FOR HARD COPY REFERENCE!

  NEW IN 2.90:
  
    * numerous optimizations for the AirHarp; specifically, for the AirHarp v4 with integral synthesis.
    * MIDI program changes are now possible with the AirHarp by using the "modifier" button alone.
    * autoDetectUSB: when active, monitors supply voltage via a dual 22k voltage divider on pin A7.  sets USB_MIDI high if below a threshold.
    * PROBLEM: sketch size (16024 of 30720 max) is likely culprit for lack of runtime code execution; specifically, autoDetectUSB feature.

  NEW IN 2.88:
  
    * better handling of debugMode (formerly "serialDebugOn"/"midiOutputOn").
    * added majorSevenMode (for Lascia ch'io pianga).  this converts the vii* chord to VII.

  NEW IN 2.87:
  
    * bug in AutoHarpMode's handing of moodInvertMode fixed.

  NEW IN 2.86:
  
    * all possible device-specific variables have been converted from #defines to integers.
    * device profiles are now configured by functions, selected by the DEVICE_PROFILE var.

  NEW IN 2.85:
    
    * MAJOR BUG FIX!!!! [in proxDetect()]
    * support for ultrasound AirHarps.

  NEW IN 2.83:

    * transpose on button press.
    * optimized to work with infrared backscatter (no major modifications to firmware required).

  NEW IN 2.82:

    * servo sweep lidar (single detector, single laser).
 
  NEW IN 2.8:
 
    * USB MIDI output thanks to the genius of MICHAEL KRZYZANIAK!!!  :D

  NEW IN 2.7:

    * rapid arpeggiation pseudo-polyphony (for piezo output).
    * multi-pass proximity detection for increased precision (allows threshold margins to be set lower, increasing sensitivity).
    * support for passive shadow harps such as the pinhole-based PocketHarp.

  NEW IN 2.6:

    * monophonic n-length arpeggiator.
    * piezo sound frequencies now derived from MIDI note numbers; allows transposition & arpeggiation to affect piezo output.

  TO DO LIST:
    * un-double midiPitchTable[]

*/


#include <stdio.h>
#include <math.h>

// device profile names
#define STICKHARP_PRO                 0
#define STICKHARP                     1
#define STICKHARP_MINI                2
#define SHADOW_HARP                   3
#define ULTRASOUND_AIRHARP            4
#define COMBO_AIRHARP                 5
#define HALOHARP                      6

// device profile
//int DEVICE_PROFILE = STICKHARP_PRO;
int DEVICE_PROFILE = COMBO_AIRHARP;
//int DEVICE_PROFILE = HALOHARP;

#define PRODUCT_ID 0xF0, 0x7D, 'H', 'a', 'l', 'o', ' ', 'H', 'a', 'r', 'p', 0xF7

#define MAXSTRINGS                    8
#define MAXSCALETONES                 7
#define MAXBUTTONS                    8
#define MAX_MIDI_CHANNELS             2

#define MIDI        0
#define USB_MIDI    1
#define LYRASYNTH   2

// ultrasonic rangefinder types
#define MAXBOTIX_LVEZ  0
#define MAXBOTIX_HRLV  1
#define PARALLAX_PING  2
#define SHARP_IR       3

// device profile vars - filled on setup by the appropriate function
int NUMSTRINGS,
    NUM_MIDI_CHANNELS = MAX_MIDI_CHANNELS,
    NUMSCALETONES,
    NUMBUTTONS,
    midiOutputType,
    autoDetectUSB,
    ACTIVE_HARP,
    ANALOG_SENSORS,
    PWM_SENSORS,
    TRIGGER_ON_POSITIVE,
    DELAY_BEFORE_AUTOCALIBRATION,
    RECALIBRATE_EVERY_SCAN,
    ULTRASOUND_HARP,
    ULTRASOUND_SENSOR_TYPE,
    ULTRASOUND_RANGE_THRESHOLD,
    ULTRASOUND_INSENSITIVITY_REGION, // Maxbotix rangefinder will not return a value less than this (first ~5-6 inches return this value)
    VISIBLE_INDICATORS,
    PROPORTIONAL_DYNAMICS,
    defaultMidiVelocity = 127,
    THEREMIN_MODE,
    NONLINEAR_MODE,
    AutoHarpMode,  // arpeggiate chords according to analog input (for AirHarp).
    AutoChordMode, // play a chord (or at least a chord root) when a note is triggered.  use with AutoHarpMode is optional.
    RandomArpMode, // choose a chord component randomly, but allow proximity-based octave and velocity selection.
    AirHarpStringSpacing,
    jitterCorrect,
    alwaysTriggeredMode,
    beaconMode,
    chordChannel,
    strumChannel,
    defaultChordPatch,
    defaultStrumPatch,
    currentChordPatch,
    currentStrumPatch,
    InsaneMode = 0,
    AutoFadeNotes = 0,
    logFade,
    fadeDecrement, // for AutoFadeNotes
    SCAN_ITERATIONS,  // number of passes to average for proxDetect() scan
    CALIBRATE_ITERATIONS,
    cycleDelay,
    capChargeDelay,
    SoundOutPinRestState,
    midiPitchMin = 21,
    midiPitchMax = 108,
    midiSendDelay = 20, // wait this many ms after sending any MIDI message (default=20)
    delayAfterRangingMicroseconds = 10;
int sensorPins[MAXSTRINGS];
int lampPins[MAXSTRINGS];
int buttonPins[MAXBUTTONS];
int buttonStates[MAXBUTTONS];
int buttonStatesOld[MAXBUTTONS];
float ThresholdCoefficient,
      ThresholdOffset;



void configureAirHarp()
{
  NUMSTRINGS = 1;
  NUM_MIDI_CHANNELS = MAX_MIDI_CHANNELS;
  midiOutputType = MIDI; // MIDI, USB_MIDI or LYRASYNTH
  autoDetectUSB = 0;
  chordChannel = 1;
  strumChannel = 0;
  defaultChordPatch = 92; // 92=bowed pad
  defaultStrumPatch = 46; // 46=Orchestral Harp; 8-15=Chromatic Perc
  defaultMidiVelocity = 117;
  NUMSCALETONES = 14;
  NUMBUTTONS = 6;
  ACTIVE_HARP = 0; // 1 for active IR; 0 for Maxbotix ultrasound
  ANALOG_SENSORS = 1;
  PWM_SENSORS = 0;
  TRIGGER_ON_POSITIVE = 0;
  DELAY_BEFORE_AUTOCALIBRATION = 0;
  RECALIBRATE_EVERY_SCAN = 0;
  ULTRASOUND_HARP = 1;
  ULTRASOUND_SENSOR_TYPE = MAXBOTIX_LVEZ;
  //ULTRASOUND_SENSOR_TYPE = SHARP_IR;
  //ULTRASOUND_SENSOR_TYPE = MAXBOTIX_HRLV;
  if (ULTRASOUND_SENSOR_TYPE == SHARP_IR)
  {
    ULTRASOUND_RANGE_THRESHOLD = 850; // 48 = 24" (2 ft.) for LV-EZ; 157 for HRLV
    ULTRASOUND_INSENSITIVITY_REGION = 500; // 11 is the standard value for LV-EZ1 !!!  (57 is standard for HRLV)
    AirHarpStringSpacing = 20; // 4 is the standard value!
  }    
  else if (ULTRASOUND_SENSOR_TYPE == MAXBOTIX_HRLV)
  {
    ULTRASOUND_RANGE_THRESHOLD = 157; // 48 = 24" (2 ft.) for LV-EZ; 157 for HRLV
    ULTRASOUND_INSENSITIVITY_REGION = 57; // 11 is the standard value for LV-EZ1 !!!  (57 is standard for HRLV)
    AirHarpStringSpacing = 4; // 4 is the standard value!
  }
  else
  {
    ULTRASOUND_RANGE_THRESHOLD = 56; // 48 = 24" (2 ft.) for LV-EZ; 157 for HRLV
    ULTRASOUND_INSENSITIVITY_REGION = 11; // 11 is the standard value for LV-EZ1 !!!  (57 is standard for HRLV)
    AirHarpStringSpacing = 4; // 4 is the standard value!
  }
  jitterCorrect = 1; // try to correct jitter?
  VISIBLE_INDICATORS = 0;
  PROPORTIONAL_DYNAMICS = 0;
  InsaneMode = 0;
  THEREMIN_MODE = 0;
  NONLINEAR_MODE = 0;
  SCAN_ITERATIONS = 3; // number of passes to average for proxDetect() scan
  CALIBRATE_ITERATIONS = 0;
  AutoHarpMode = 1; // play individual note in current chord based on proximity (set to '1' for Combo AirHarp)
  AutoChordMode = 0; // play constant chords
  RandomArpMode = 0;
  alwaysTriggeredMode = 0;
  beaconMode = 1;
  AutoFadeNotes = 0; // fade each note at a predefined rate; notes decay automatically independent of performance input
  logFade = 0; // fade logarithmically (divide by 2 every iteration)
  fadeDecrement = 1; // for AutoFadeNotes
  cycleDelay = 0; // 20
  capChargeDelay = 0;
  sensorPins[0] = 0;
  sensorPins[1] = 0;
  sensorPins[2] = 0;
  sensorPins[3] = 0;
  sensorPins[4] = 0;
  sensorPins[5] = 0;
  sensorPins[6] = 0;
  sensorPins[7] = 0;
  lampPins[0] = 9;
  lampPins[1] = 9;
  lampPins[2] = 9;
  lampPins[3] = 9;
  lampPins[4] = 9;
  lampPins[5] = 9;
  lampPins[6] = 9;
  lampPins[7] = 9;
  buttonPins[0] = 6; // transpose up button
  buttonPins[5] = 7; // transpose down button
  buttonPins[1] = 2; // chord select buttons
  buttonPins[2] = 3; // "
  buttonPins[3] = 4; // "
  buttonPins[4] = 5; // pinkie button (flips chord mood)
  SoundOutPinRestState = 0;
  ThresholdCoefficient = 0;
  ThresholdOffset = 0;
}



// major keys (for auto-transposition)
#define KEY_OF_C        0
#define KEY_OF_C_SHARP  1
#define KEY_OF_D_FLAT   1
#define KEY_OF_D        2
#define KEY_OF_D_SHARP  3
#define KEY_OF_E_FLAT   3
#define KEY_OF_E        4
#define KEY_OF_F        5
#define KEY_OF_F_SHARP  6
#define KEY_OF_G_FLAT   6
#define KEY_OF_G        7
#define KEY_OF_G_SHARP  8
#define KEY_OF_A_FLAT   8
#define KEY_OF_A        9
#define KEY_OF_A_SHARP  10
#define KEY_OF_B_FLAT   10
#define KEY_OF_B        11

#define DEFAULT_MIDI_TONIC    60 // 60 = middle C


// I/O pins
int SoundOutPin = 13, // attach piezo speaker to this pin
    supplyVoltageMonitorPin = A7,
    pwmPin = 10; // for reading ultrasound with pulseIn()
// note: the MIDI output pin is, by necessity, pin 1 (a.k.a. "TX1"),
// because this is the hardwired serial transmit pin on the Arduino Nano.
// (use whichever pin says "TX" for your MIDI output).

// global vars
int midiNote,
    TRANSPOSITION_OFFSET = KEY_OF_C,
    midiTonic = DEFAULT_MIDI_TONIC + TRANSPOSITION_OFFSET,
    PiezoSoundOn = 0,
    midiDebugOn = 0,
    debugMode = 0,
    ChordTriggerMode = 1,
    modeSwitchable = 0,
    aftertouchOn = 0,
    arpState = 0,
    moodInvertMode = 0,
    majorSevenMode = 0, // turns the 7 chord from vii* (diminished) to VII (Major)
    piezoDelay = 50, //50
    standardDelay = 10, // delay per scan cycle (post-scan)
    longDelay = 100;

int scale[] = { 0, 2, 4, 5, 7, 9, 11, 12, 14, 16, 17, 19, 21, 23 };  // scale mode expressed in semitone offsets from tonic
int invertTable[] = { -1, 1, 1, -1, -1, 1, 1 }; // semitone offsets to invert mood of thirds
char midiVelocities[MAX_MIDI_CHANNELS][128];
char midiVelocitiesOld[MAX_MIDI_CHANNELS][128];

float thresholds[MAXSTRINGS];
int triggered[MAXSTRINGS];
float sensorValues[MAXSTRINGS],
      sensorValuesOld[MAXSTRINGS],
      lampDarkVals[MAXSTRINGS],
      lampLitVals[MAXSTRINGS];

unsigned int patchButtonPressDuration = 0,
             patchButtonPressThreshold = 100000; // continuous cycles before button hold results in patch change
                                                 // 100 was good value to activate; set to 100,000 to effectively deactivate patch changes

int arpLen = 16;
int arpPattern[] = { 1, 1, 3, 3, 5, 5, 1, 1, 3, 3, 5, 5, 1, 1, 3, 3 // "Anticipation"
                     //1, 3, 5, 1, 3, 5, 1, 3 // "What I Could Never Say"
                   }; 


// pitch formula: f = 2 ^ (tone / 12) * 440
// scale pitches, calculated by me:
float pitchTable[12] = { 440.000000, // A
                         466.163757, // A#/Bb
                         493.883301, // B
                         523.251160, // C
                         554.365234, // C#/Db
                         587.329529, // D
                         622.253967, // D#/Eb
                         659.255127, // E
                         698.456482, // F
                         739.988831, // F#/Gb
                         783.990845, // G
                         830.609375 // G#/Ab
                       };

unsigned int midiPitchTable[128]; // was "double"


void setup()
{
  analogReference(DEFAULT);
  //pinMode(SoundOutPin, OUTPUT);
  //digitalWrite(SoundOutPin, SoundOutPinRestState);  // shut up!  :?P
  
  // configure device-specific variables for appropriate device profile
  if (DEVICE_PROFILE == COMBO_AIRHARP) configureAirHarp();
  
  if (autoDetectUSB) detectUSBbyInputVoltage();

  if (debugMode)
  {
    Serial.begin(9600);
  }
  /*
  else if (midiOutputType == USB_MIDI)
  {
    //Serial.begin(115200);
    Serial.begin(31250);
    const uint8_t productID[] = {
      PRODUCT_ID    };
    Serial.write(productID, sizeof(productID));
  }
  else if (midiOutputType == LYRASYNTH)
  {
    Serial.begin(9600);
  }
  else Serial.begin(31250); //  Set MIDI baud rate:
  */

  if (!ULTRASOUND_HARP) delay(DELAY_BEFORE_AUTOCALIBRATION); // gives performer time to stand clear
  
  // autocalibrate
  autoCalibrate();
  
  zeroMidiVelocities();
  copyNewToOld(); // zeroes midiVelocitiesOld as well

  currentChordPatch = defaultChordPatch;

  currentStrumPatch = defaultStrumPatch;
  
  if (beaconMode) activateBeaconMode();
}


void loop()
{
  //allLampsOn(); // photogenic mode
  lightHarp();
  //airHarpDuo();
}


// turns on the device's LED
void activateBeaconMode()
{
  pinMode(8, OUTPUT);
  pinMode(9, OUTPUT);
  digitalWrite(8, HIGH);
  digitalWrite(9, LOW);
}


void calibrate(unsigned int i)  // i = light string #
{
  // poll sensors by method appropriate to sensor type;
  // store values in sensorValues[] and thresholds[]
  triggered[i] = 0;
  
  float totalValue = 0,
  maxValue = 0,
  minValue = 1000000;   
  for (unsigned int index = 0; index < CALIBRATE_ITERATIONS; index++)
  {
    float value = 0;
    //if (ACTIVE_HARP) value = proxDetect(i);
    //else value = passiveDetect(i);
    value = proxDetect(i);
    totalValue += value;
    if (value > maxValue) maxValue = value;
    if (value < minValue) minValue = value;
  }
  float avgValue = totalValue / CALIBRATE_ITERATIONS;    
  if (debugMode)
  {
    Serial.print(" min: ");
    Serial.print(minValue);
    Serial.print("; max: ");
    Serial.print(maxValue);
    Serial.print("; avg: "); 
    Serial.print(avgValue);
    Serial.println();
  }
  sensorValues[i] = avgValue;
  if (ACTIVE_HARP) // always triggers on a positive differential (though directionality of differntial does matter)
  {
    thresholds[i] = maxValue; // set the treshold to the highest value obtained during calibration
    ///////////////thresholds[i] = lampLitVals[i]; // if higher-than-ambient rather than differential triggering
    ThresholdOffset = thresholds[i] * ThresholdCoefficient; //diff(avgValue, maxValue); // now add a little margin to prevent spurrious false positives
  }
  else if (TRIGGER_ON_POSITIVE)  // passive harp that triggers when sensors read high
  {
    thresholds[i] = maxValue; // set the treshold to the highest value obtained during calibration
    ThresholdOffset = ThresholdCoefficient * thresholds[i]; // now add a little margin to prevent spurrious false positives
  }
  else if (!ULTRASOUND_HARP) // passive harp that triggers when sensors read low
  {
    thresholds[i] = minValue; // set the treshold to the lowest value obtained during calibration    
    ThresholdOffset = ThresholdCoefficient * thresholds[i]; // now subtract a little margin to prevent spurrious false positives
  }
}


void autoCalibrate()
{
  for (int i = 0; i < NUMSTRINGS; i++)
  {     
    if (ULTRASOUND_HARP) thresholds[i] = ULTRASOUND_RANGE_THRESHOLD;
    else calibrate(i);
    //delay(standardDelay);
  }
  if (debugMode) Serial.println();
}

void recalibrate()
{
  // all this does is set the thresholds to the current light levels
  // it doesn't perform a new scan - it just uses the data from the last scan
  for (int i = 0; i < NUMSTRINGS; i++)
  {     
    //triggered[i] = 0;
    //if (ACTIVE_HARP) sensorValues[i] = proxDetect(i);
    //else sensorValues[i] = passiveDetect(i);
    thresholds[i] = sensorValues[i];
    //delay(standardDelay);
  }
  //if (debugMode) Serial.println();
}
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

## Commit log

2021-03-22 Added 3D CAD for printable enclosure.
    [AirHarp Pico 013 PCB.stl, AirHarp Pico 013 assembled.stl, AirHarp Pico 013 bottom.stl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]
2021-03-22 Added firmware for Teensy 2.0 microcontroller.
2021-03-22 Added unit cost breakdown / bill of materials.
    [AirHarp Pico unit cost breakdown.xlsx]
2021-03-22 Added printed circuit boards (PCBs).
    [AirHarp Pico 1.001.brd, AirHarp Pico 1.001.sch]
2021-12-01 Added AirHarp Lira assembly manual
    Even though this manual is for the AirHarp Lira, not the AirHarp Pico, it may be of use to someone who is new to hobby electronics. Given the numerous similarities between the two devices, it may be 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

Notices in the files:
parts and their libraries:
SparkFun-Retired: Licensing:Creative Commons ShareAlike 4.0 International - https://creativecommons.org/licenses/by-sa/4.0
